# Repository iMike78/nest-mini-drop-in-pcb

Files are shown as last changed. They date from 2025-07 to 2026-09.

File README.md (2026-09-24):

<div align="right">
  <details>
    <summary >🌐 Language</summary>
    <div>
      <div align="center">
        <a href="https://openaitx.github.io/view.html?user=iMike78&project=nest-mini-drop-in-pcb&lang=en">English</a>
        | <a href="https://openaitx.github.io/view.html?user=iMike78&project=nest-mini-drop-in-pcb&lang=zh-CN">简体中文</a>
        | <a href="https://openaitx.github.io/view.html?user=iMike78&project=nest-mini-drop-in-pcb&lang=zh-TW">繁體中文</a>
        | <a href="https://openaitx.github.io/view.html?user=iMike78&project=nest-mini-drop-in-pcb&lang=ja">日本語</a>
        | <a href="https://openaitx.github.io/view.html?user=iMike78&project=nest-mini-drop-in-pcb&lang=ko">한국어</a>
        | <a href="https://openaitx.github.io/view.html?user=iMike78&project=nest-mini-drop-in-pcb&lang=hi">हिन्दी</a>
        | <a href="https://openaitx.github.io/view.html?user=iMike78&project=nest-mini-drop-in-pcb&lang=th">ไทย</a>
        | <a href="https://openaitx.github.io/view.html?user=iMike78&project=nest-mini-drop-in-pcb&lang=fr">Français</a>
        | <a href="https://openaitx.github.io/view.html?user=iMike78&project=nest-mini-drop-in-pcb&lang=de">Deutsch</a>
        | <a href="https://openaitx.github.io/view.html?user=iMike78&project=nest-mini-drop-in-pcb&lang=es">Español</a>
        | <a href="https://openaitx.github.io/view.html?user=iMike78&project=nest-mini-drop-in-pcb&lang=it">Italiano</a>
        | <a href="https://openaitx.github.io/view.html?user=iMike78&project=nest-mini-drop-in-pcb&lang=ru">Русский</a>
        | <a href="https://openaitx.github.io/view.html?user=iMike78&project=nest-mini-drop-in-pcb&lang=pt">Português</a>
        | <a href="https://openaitx.github.io/view.html?user=iMike78&project=nest-mini-drop-in-pcb&lang=nl">Nederlands</a>
        | <a href="https://openaitx.github.io/view.html?user=iMike78&project=nest-mini-drop-in-pcb&lang=pl">Polski</a>
        | <a href="https://openaitx.github.io/view.html?user=iMike78&project=nest-mini-drop-in-pcb&lang=ar">العربية</a>
        | <a href="https://openaitx.github.io/view.html?user=iMike78&project=nest-mini-drop-in-pcb&lang=fa">فارسی</a>
        | <a href="https://openaitx.github.io/view.html?user=iMike78&project=nest-mini-drop-in-pcb&lang=tr">Türkçe</a>
        | <a href="https://openaitx.github.io/view.html?user=iMike78&project=nest-mini-drop-in-pcb&lang=vi">Tiếng Việt</a>
        | <a href="https://openaitx.github.io/view.html?user=iMike78&project=nest-mini-drop-in-pcb&lang=id">Bahasa Indonesia</a>
        | <a href="https://openaitx.github.io/view.html?user=iMike78&project=nest-mini-drop-in-pcb&lang=as">অসমীয়া</
      </div>
    </div>
  </details>

</div>

# MiciMike drop-in PCB replacement for Google Nest Mini

[MiciMike Nest Mini](https://github.com/iMike78/nest-mini-drop-in-pcb) is a drop-in PCB replacement for the ["Google Nest Mini" (Google's second-generation smart speaker with a barrel connector charging port)](https://en.wikipedia.org/wiki/Google_Nest_(smart_speakers)), but based on ESP32 and XMOS microcontrollers for running open-source firmware.

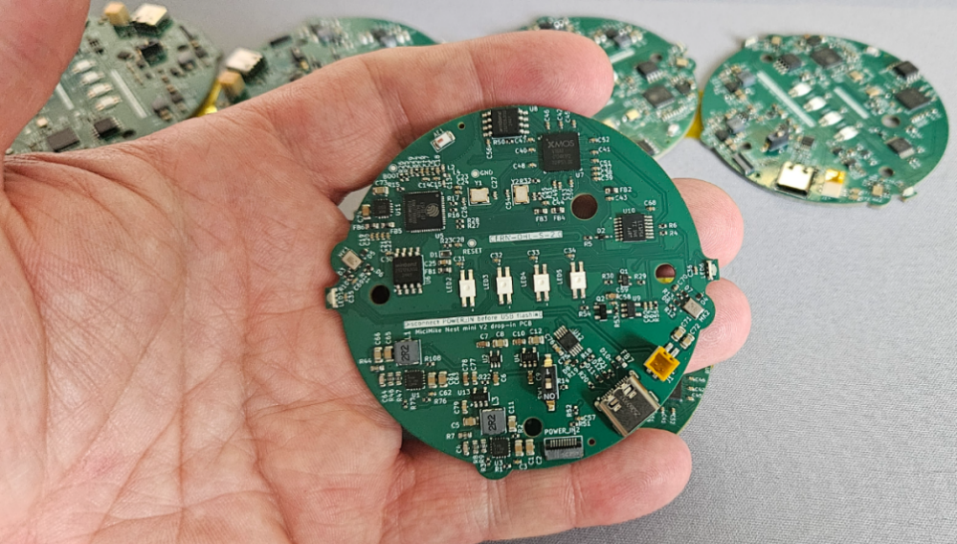
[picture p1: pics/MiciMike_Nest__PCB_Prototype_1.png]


Tip! If you are instead looking for a similar drop-in PCB replacement for the "Google Home Mini" (Google's first-generation smart speaker hardware with a Micro-USB charging port) then check out the sister-project at https://github.com/iMike78/home-mini-v1-drop-in-pcb

Both of these are fully open-source hardware projects, taking some concept inspiration from the [Onju Voice](https://github.com/justLV/onju-voice) however aiming to follow [Open Home Foundation's open voice assistants standard  with Home Assistant Voice Preview Edition as reference](https://www.home-assistant.io/blog/2024/12/19/voice-preview-edition-the-era-of-open-voice/) for PCB designs and specifications.

# Project scope

The goal of this project and repository (which is similar to the [Onju Voice](https://github.com/justLV/onju-voice) but under a fully open-source hardware license) is to design a custom drop-in replacement PCB (Printed Circuit Board) for the Google Nest Mini (2nd Gen).

This is primarly targeting people looking to convert/repurpose their old Google Nest Mini smart speakers into open-source hardware for [Voice Control of Home Assistant](https://www.home-assistant.io/voice_control/) and/or media player speaker output for [Music Assistant](https://www.music-assistant.io), (the hardware can however probably also be used with other applications as well with other firmware as it is based on the popular Espressif ESP32 platform).

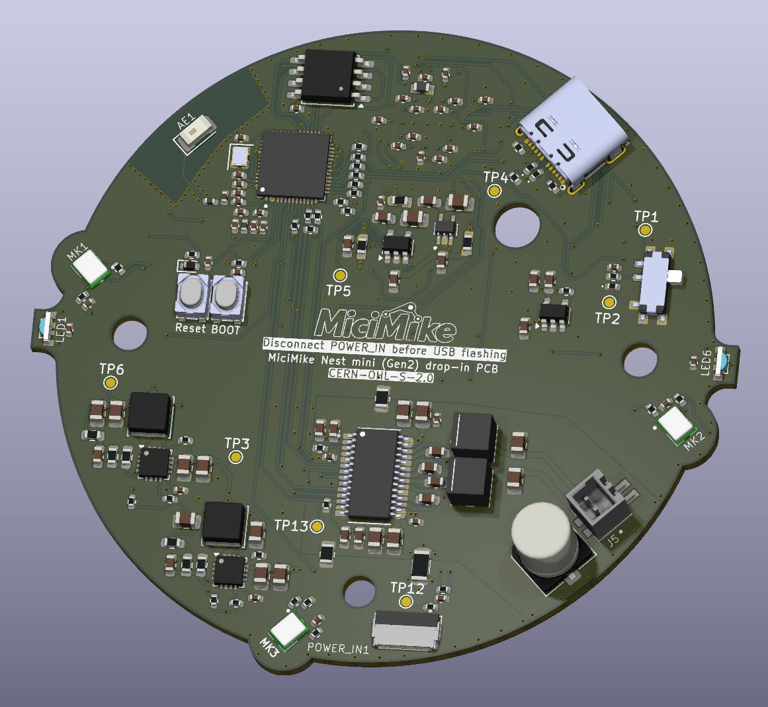
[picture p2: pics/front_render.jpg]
First test PCB


The hardware design will (similar to [Home Assistant Voice Preview Edition](https://www.home-assistant.io/blog/2024/12/19/voice-preview-edition-the-era-of-open-voice/)) integrate an ESP32-S3 SoC for WiFi, BLE, and [onboard wake-word detection](https://www.home-assistant.io/voice_control/about_wake_word/) (using no-code [ESPHome firmware](https://esphome.io/)) + an XMOS xCORE XU316 chip for advanced audio processing (with custom firmware for microphone cleanup offloading for better voice recognition capabilities by using using locally running algorithms for Noise Suppression, Acoustic Echo Cancellation, Interference Cancellation, and Automatic Gain Control).

Functionality-wise it is made to mostly hardware comatible with the [Home Assistant Voice Preview Edition (a.k.a. Home Assistant Voice PE](https://www.home-assistant.io/blog/2024/12/19/voice-preview-edition-the-era-of-open-voice/) reference design (which has been released as open-source hardware design from Open Home Foundation in coolaboration with Nabu Casa). The main difference will be due to constraints defined by the Google Nest Mini enclosure and comonents, (i.e. the nest-mini-drop-in-pcb project hardware design will be limited by the same type of physical capacity inputs as the original hardware from Google).

As such the scope of this project/repository is not to develop new features/functions for the ESPHome firmware, so if you want that then you instead need to turn to the firmware development of the Home Assistant Voice Preview Edition as well as to the upstream ESPHome mainline code:

- https://github.com/esphome/home-assistant-voice-pe
  - https://github.com/esphome/esphome
      - https://github.com/esphome/feature-requests

## Request for collaboration

If you have some experience with PCB layout design, (and epecially with PCB routing, ground pouring, or noise-sensitive digital+analog layouts), **your help is highly appreciated**! Please feel free to open a new issue, submit suggestions/requests, and add input/feedback to existing issues, or fork this repository.

For more information about the concept/idea see and contribute to related discussion also see this Home Assistant community forum thread:

- https://community.home-assistant.io/t/any-news-on-alternative-to-onju-voice-pcb-repacement-design-for-google-nest-home-mini-speakers-with-added-xmos-chip-to-match-of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

### Current status

> [!CAUTION]
> This project is under active development and is **not ready for fabrication or general use**. I do not recommend using the current files to manufacture a PCB.

The hardware is currently being substantially reworked, including the addition and integration of an ESP32-C6 for Thread support. As a result, parts of the schematic are incomplete, some components and connections are not yet placed or routed on the PCB, and the schematic and PCB may not be in sync.

The current ESPHome configuration also targets an earlier hardware revision and does not match the present schematic. It should not be treated as working firmware for the current board design.

Several known and newly reported hardware issues are being reviewed and will need to be corrected before another prototype revision is considered. These include the XMOS core power supply, parts of the XMOS audio and echo-cancellation reference path, a microphone buffer connection, XMOS debug-header voltage levels, mute detection, ESP32-C6 integration, and other smaller signal-level and connectivity issues.

Development and documentation updates have been slower recently due to limited availability and work on the related Home Mini project. The README and design files will be updated as the review and redesign progress.

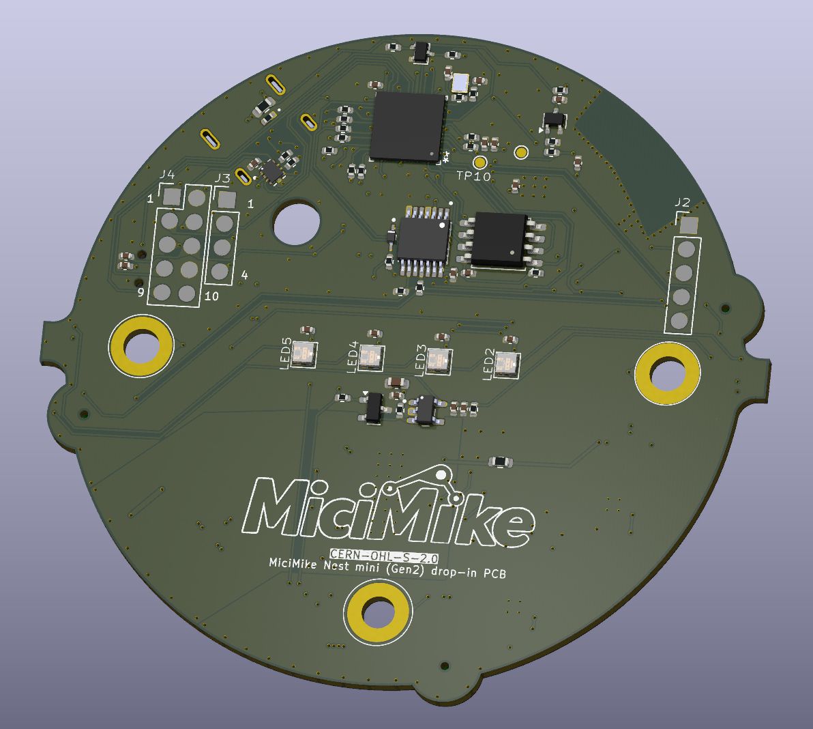
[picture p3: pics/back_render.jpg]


## Tools used

- 🛠️ KiCad 9
- 🧰 SnapEDA / LCSC for footprint sourcing

## Known hardware specifications

- 4-layer PCB
- ESP32-S3R8 bare chip (ESP32-S3 for WiFi, BLE, and onboard wake-word detection)
- XMOS XU316-1024-QF60B-C24 (XMOS XU316 xCORE DSP audio processing)
- 16 MB SPI flash (ESP32-S3)
- 4 MB SPI flash (XMOS XU316)
- Dual I²S buses (simultaneous audio input and output)
- TAS5805M (TAS5805MPWPR) stereo Class-D amplifier with integrated DSP (I2S audio, I2C control), configured for mono BTL speaker output
- 3x MEMS microphones (MMICT390200012) arranged on a 34 mm radius arc - current firmware uses 2 microphones, hardware support for a 3-microphone array is already present
- 6x SK6812 RGB LEDs
- Custom USB-C and 14V power input (Note! USB-C and barrel-connector can not be connected at the same time)
- MPR121 capacitive touch controller (used for touch input instead of ESP32-S3 native touch sensing)

---

> ⚠️ Flashing via USB-C requires disconnecting the main 14V power input. See silkscreen note on PCB for details.

## References

### Home Assistant Voice Preview Edition resources including PCB design files
- https://www.home-assistant.io/blog/2024/12/19/voice-preview-edition-the-era-of-open-voice/
  - https://voice-pe.home-assistant.io/resources/
    - https://support.nabucasa.com/hc/en-us/articles/26195279589277-Home-Assistant-Voice-Preview-Edition-PCB-design-files
      - https://raw.githubusercontent.com/NabuCasa/support/refs/heads/main/static/docs/voice/home_assistant_voice_pe_schematic_v1.0_241009.pdf
     
#### ESPHome firmware for Home Assistant Voice PE (which also use the same ESP32-S3 + XMOS XU316 combination):

- https://github.com/esphome/home-assistant-voice-pe
  - https://esphome.github.io/home-assistant-voice-pe/
- https://voice-pe.home-assistant.io/

### XMOS xCORE DSP (XU316-1024-QF60B-C24) MCU IC chip

- https://www.xmos.com/download/XU316-1024-QF60B-xcore.ai-Datasheet(3).pdf
- https://www.xmos.com/software-tools/
  - https://www.xmos.com/develop/xcore-voice
  - https://www.xmos.com/usb-multichannel-audio/
  - https://www.xmos.com/xcore-ai
 
#### XMOS firmware from the ESPHome project for the Home Assistant Voice Preview Edition hardware:

- https://github.com/esphome/voice-kit-xmos-firmware
  - https://github.com/esphome/xmos_fwk_rtos
  - https://github.com/esphome/xmos_fwk_io

## License

This project is licensed under the [CERN Open Hardware License Version 2 - Strongly Reciprocal (CERN-OHL-S v2)]
Any modified version of this hardware must also be distributed under the same license.

☕ If you’d like to support this project, feel free to [buy me a coffee on Ko-fi](https://ko-fi.com/imike78)!

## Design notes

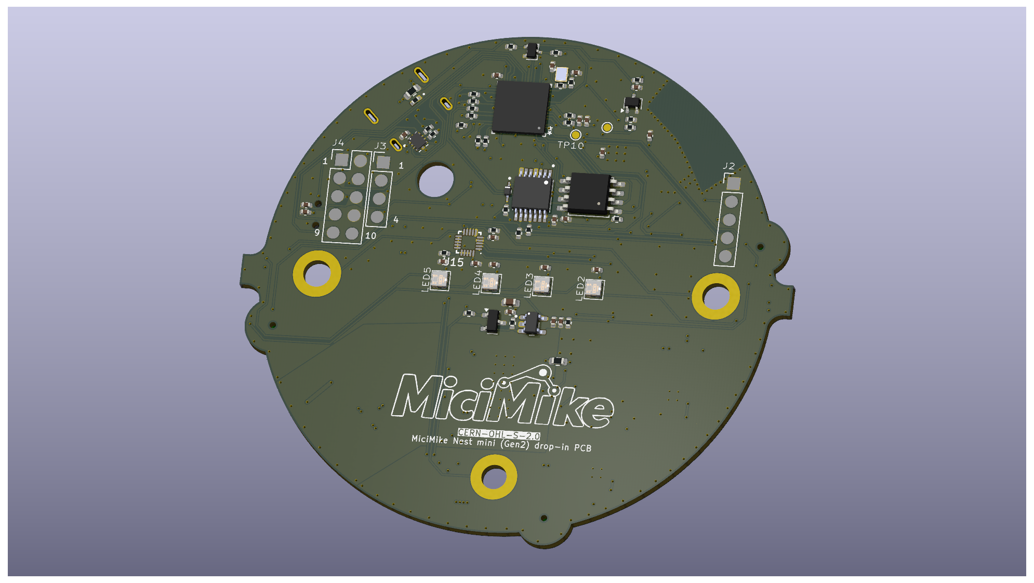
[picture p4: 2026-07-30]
pics/nest-mini-DiP-Gen2-back.png

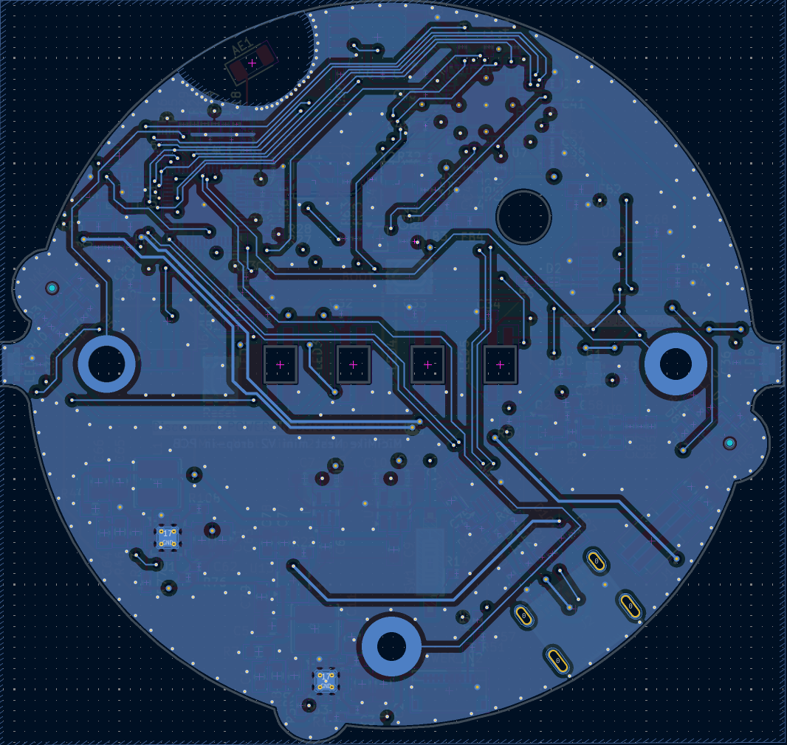
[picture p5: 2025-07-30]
pics/B_Cu.png

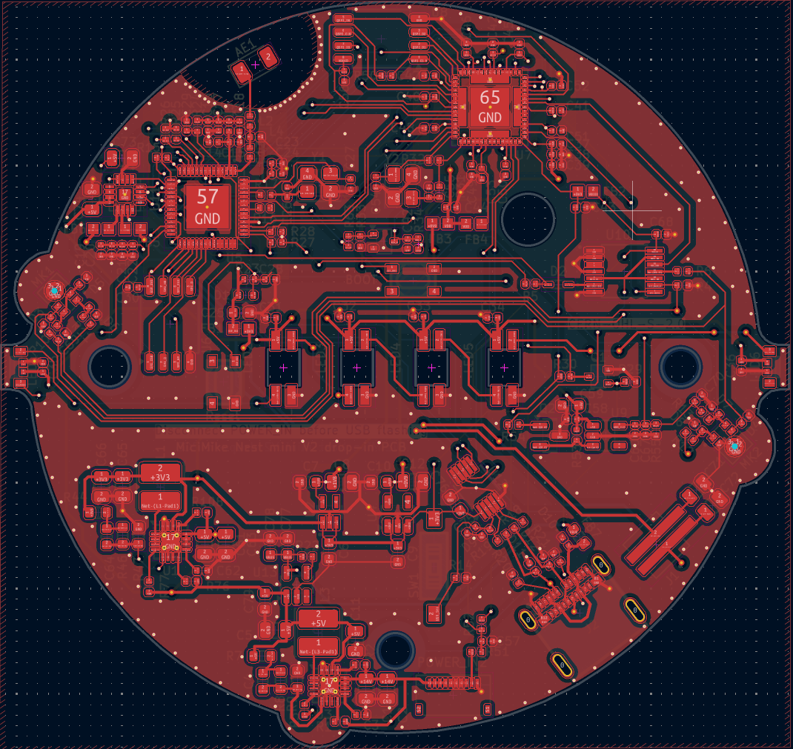
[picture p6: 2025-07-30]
pics/F_Cu.png

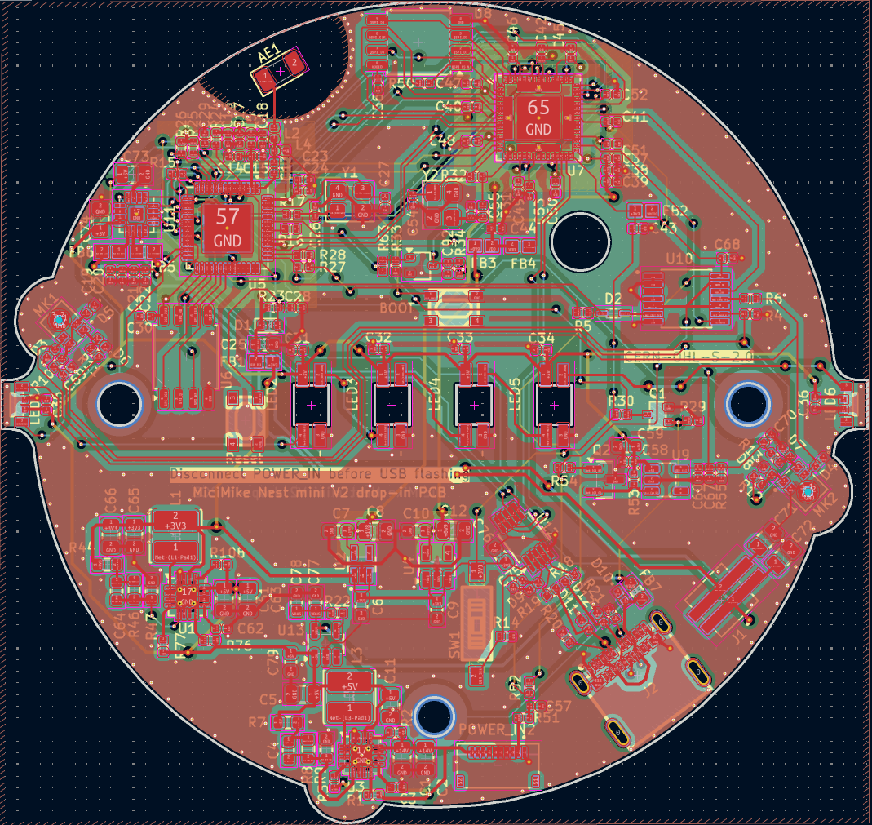
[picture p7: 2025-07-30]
pics/layout.png

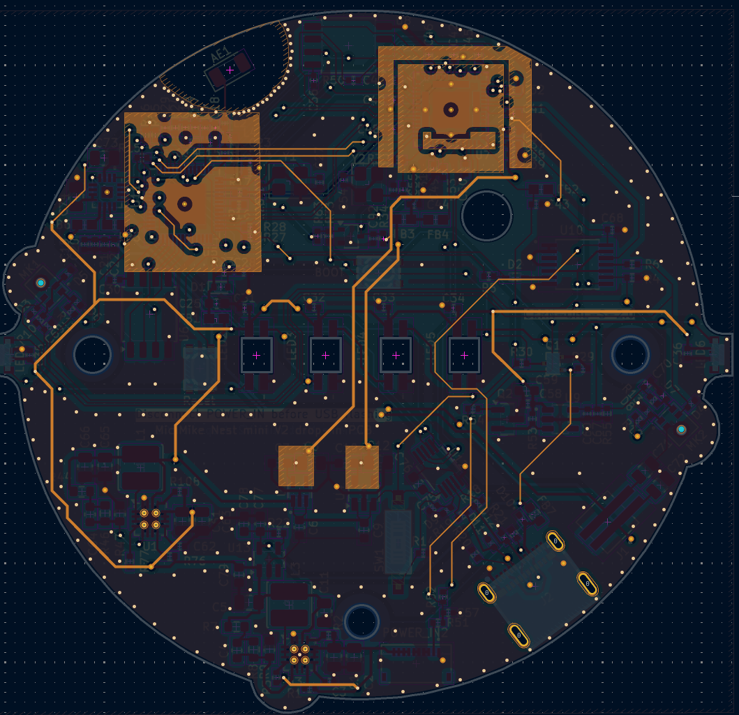
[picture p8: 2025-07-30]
pics/In2_Cu.png

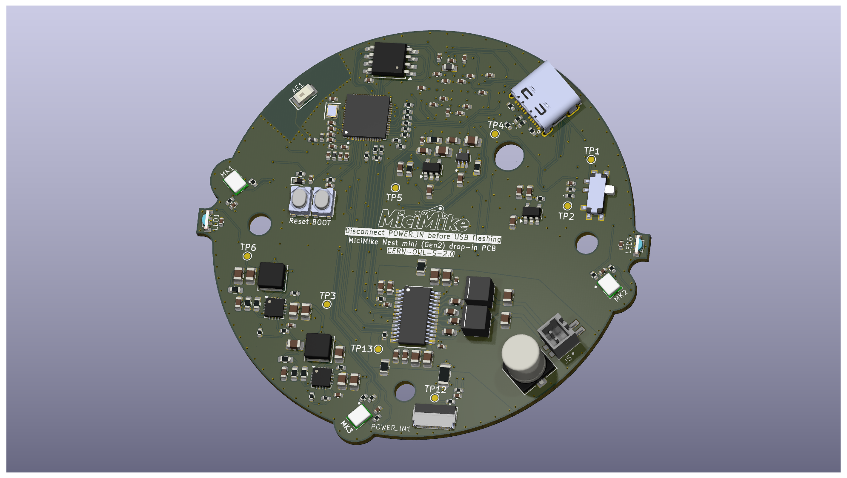
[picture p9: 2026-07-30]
pics/nest-mini-DiP-Gen2-front.png

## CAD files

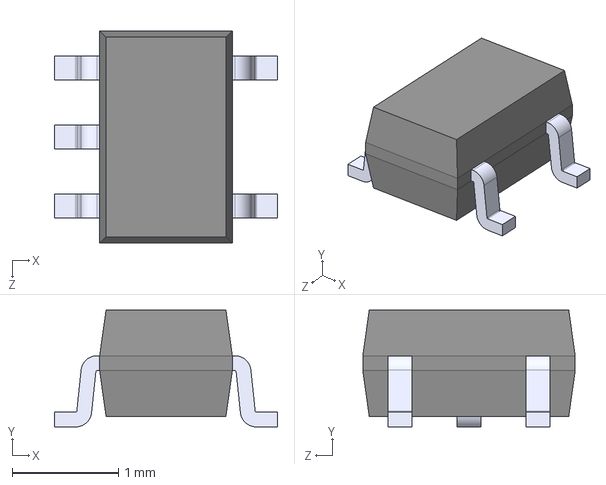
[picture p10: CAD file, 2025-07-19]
parts/MIC5365-1.8YC5-TR.step
2.10 x 1.10 x 2.00 mm

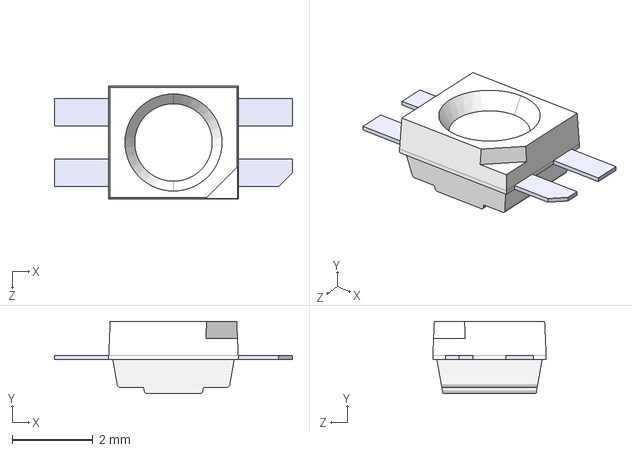
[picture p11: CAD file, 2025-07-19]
parts/SK6812-E.step
5.88 x 1.78 x 2.80 mm

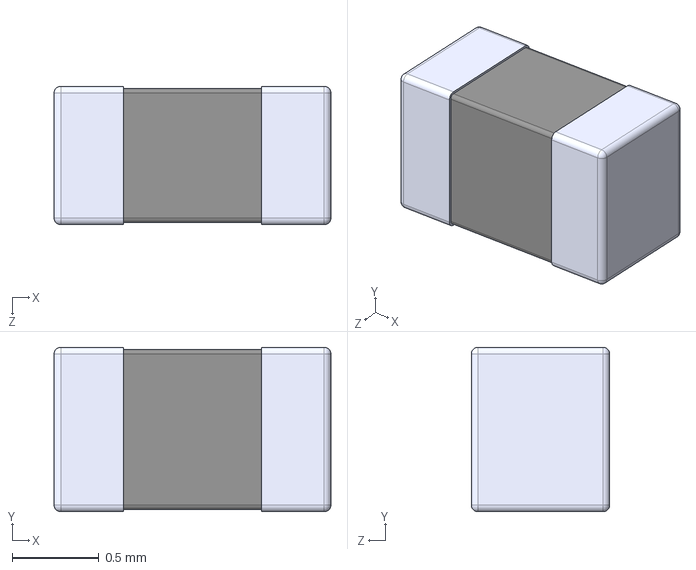
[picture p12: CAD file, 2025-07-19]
parts/BLM18PG121SN1D.step
1.60 x 0.95 x 0.8 mm

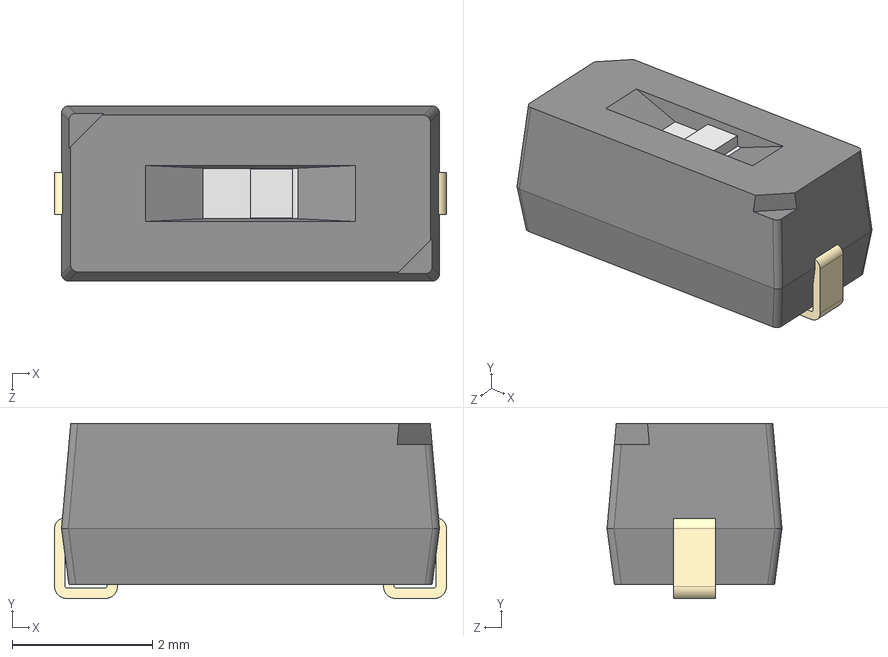
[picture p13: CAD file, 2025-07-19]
parts/CHS-01TA.step
5.60 x 2.50 x 2.50 mm
CHS-01 body
pin^CHS-01xx
switch^CHS-01xx

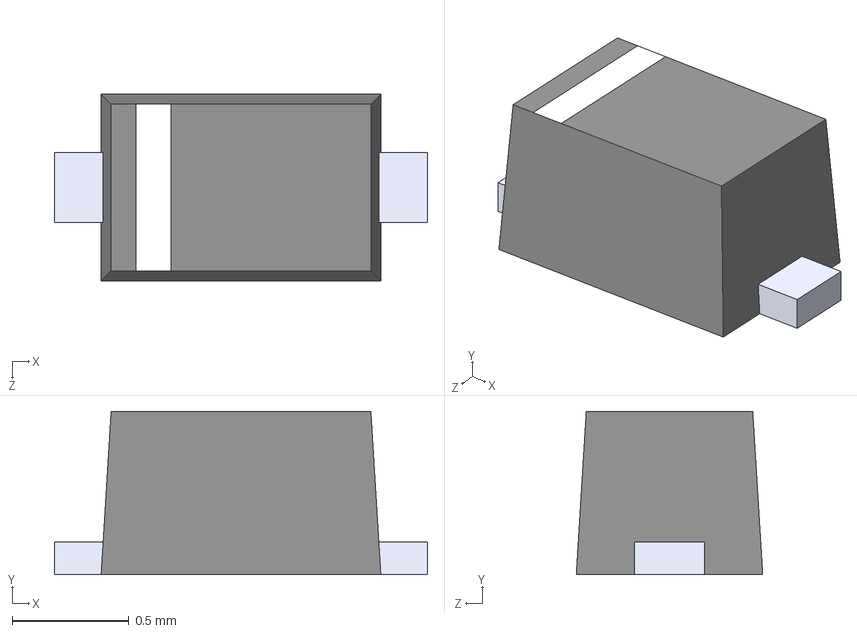
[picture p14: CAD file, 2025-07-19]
parts/RB521S30T1G.step
1.60 x 0.7 x 0.8 mm

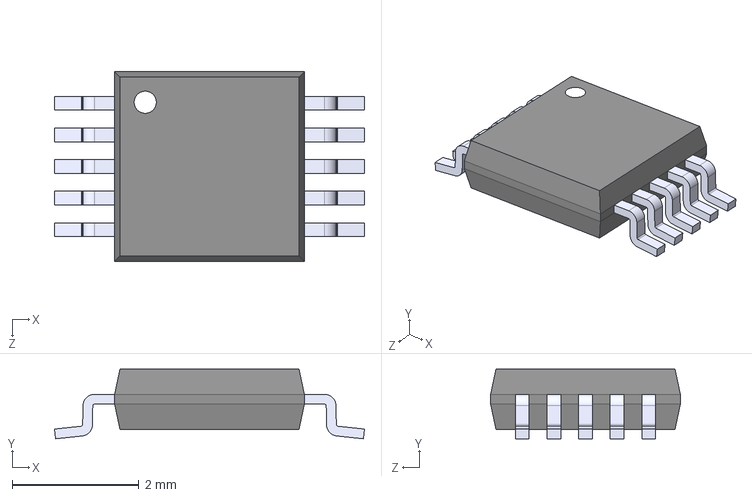
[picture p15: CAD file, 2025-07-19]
parts/FSUSB42MUX.step
4.90 x 1.10 x 3.00 mm

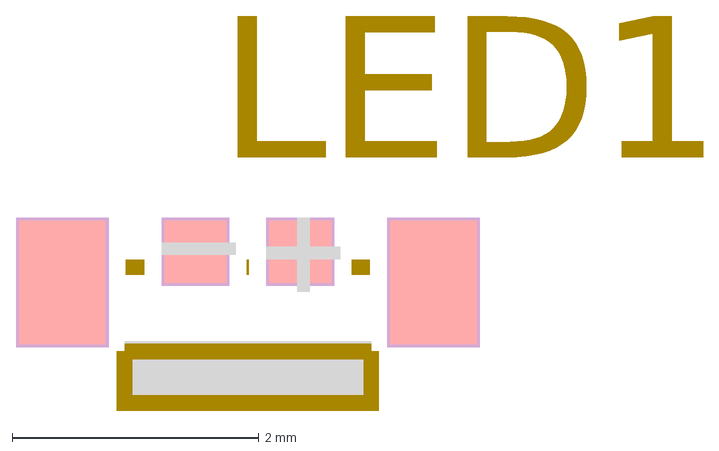
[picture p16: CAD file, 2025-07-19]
parts/SK6812D-EC3210R.dxf
LED1

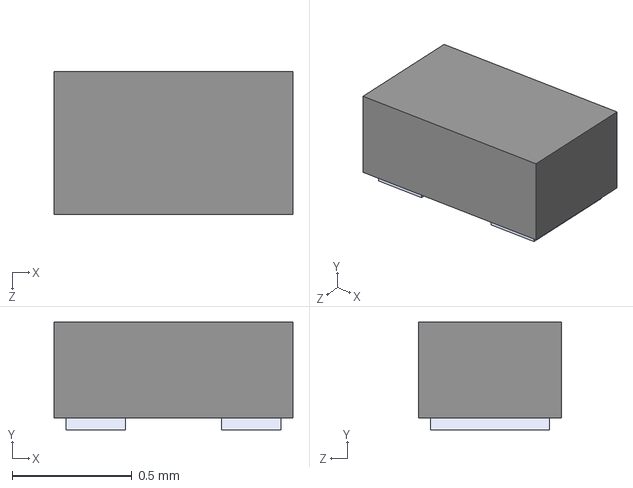
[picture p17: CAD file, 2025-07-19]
parts/TPD1E10B06DPYR.step
1.00 x 0.45 x 0.6 mm

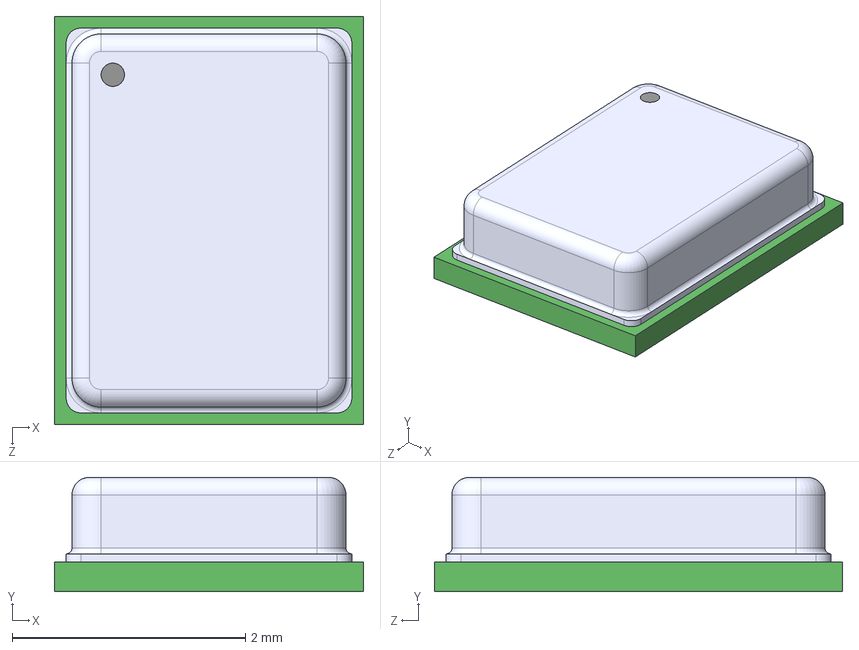
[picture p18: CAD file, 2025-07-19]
parts/T3902.step
2.65 x 0.98 x 3.50 mm

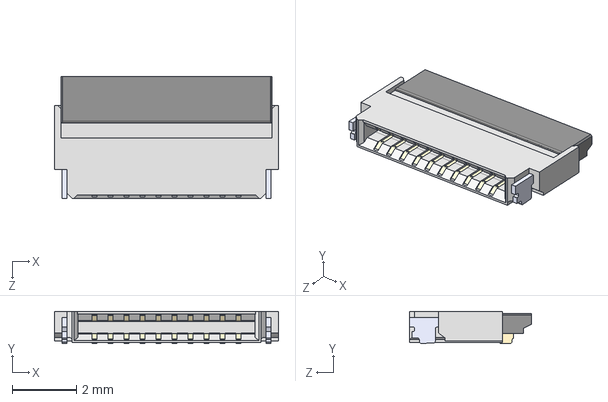
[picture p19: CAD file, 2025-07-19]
parts/FH34SRJ-10S-0.5SH_50_.step
7.00 x 1.00 x 3.80 mm

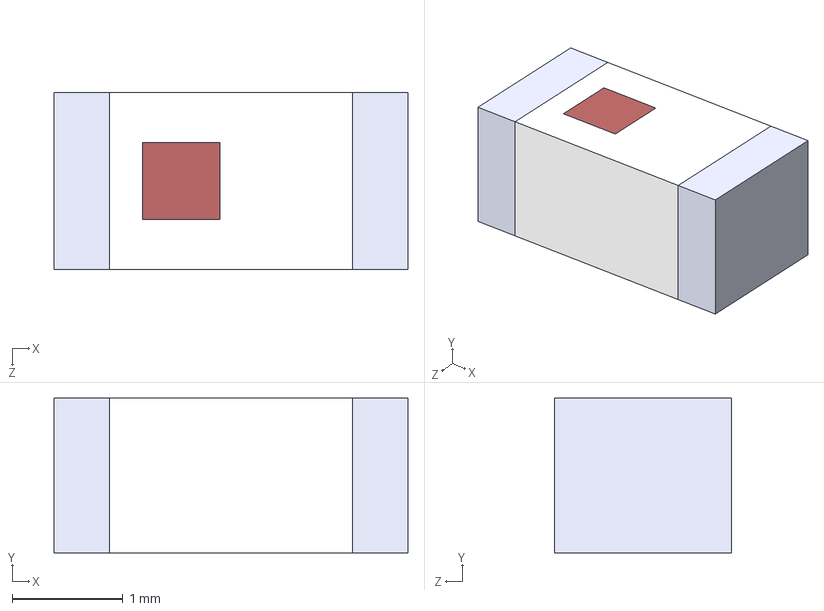
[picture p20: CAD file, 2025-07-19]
parts/2450AT18A100E.step
3.20 x 1.40 x 1.60 mm

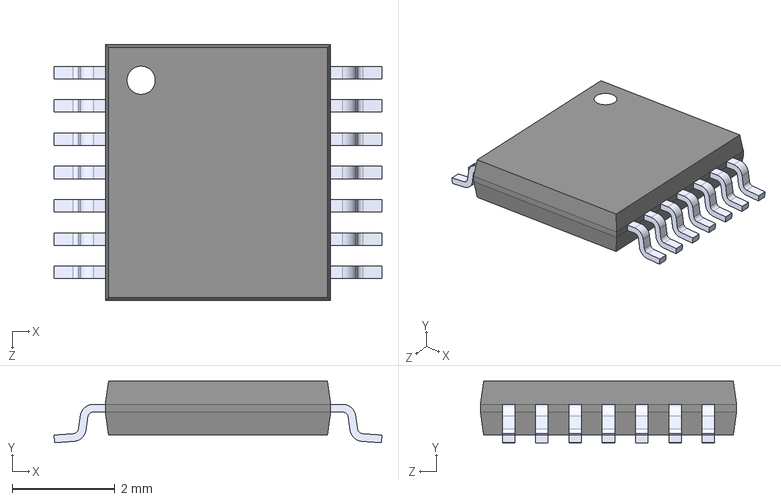
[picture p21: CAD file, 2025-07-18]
parts/SN74LVC125APWR.step
6.40 x 1.20 x 5.00 mm

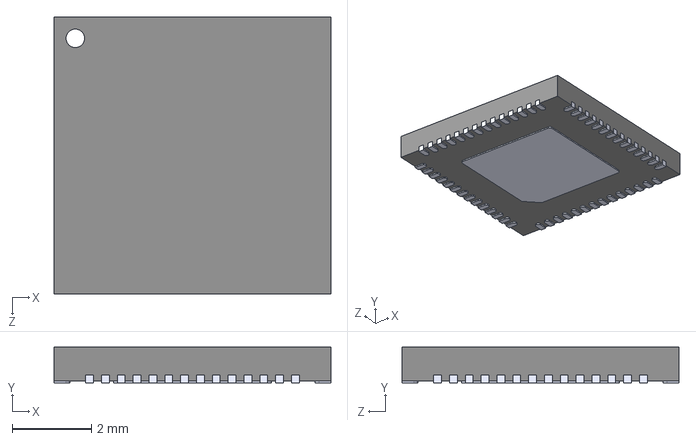
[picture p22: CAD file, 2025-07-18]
parts/ESP32-S3R8.step
7.00 x 0.9 x 7.00 mm

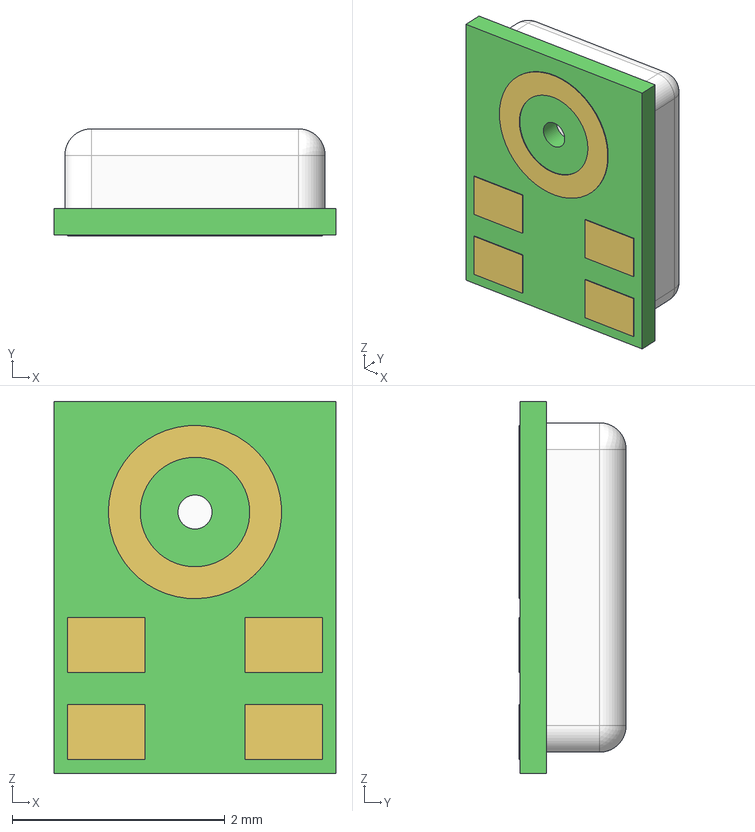
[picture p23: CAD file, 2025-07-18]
parts/DMM-3526-B-R.step
2.65 x 1.01 x 3.50 mm

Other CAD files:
parts/QFN_F60B-C24_XMO.step
parts/OBJ_SW-SMD_2P-L6.2-W2.5-LS9.4.obj
parts/SW-SMD_2P-L6.2-W2.5-LS9.4.dxf
parts/1054500101.obj
parts/1054500101.step
parts/1775443-2.stp
parts/MAX98357AETE_T.step
parts/TLV73333PDBVR.step
parts/TPS563201DDCT.step
parts/USB-C-SMD_TYPE-C-USB-18_2025-06-23.dxf
parts/USB_C_165068306/1054500101_3D.dxf

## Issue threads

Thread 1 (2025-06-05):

Will the first nest-mini-drop-in-pcb design use Dual I2S bus (same as Home Assistant Voice PE)?

Hedda, 2025-06-05:
Will the first nest-mini-drop-in-pcb design use "Dual I2S bus" (same as Home Assistant Voice PE)? As requested by @tetele for onju-voice here:

* https://github.com/justLV/onju-voice/issues/74

PS: For reference also see the somewhat related discussion here:

* https://github.com/orgs/FutureProofHomes/discussions/6

iMike78, 2025-06-11:
This isn’t really an issue, and the question is already answered — but yes, the design uses dual I²S buses, just like the Home Assistant Voice PE.
My work is strongly based on the HA VPE hardware design, so dual I²S with XMOS was a natural choice from the beginning.

Thanks for opening the thread and sharing the links, @Hedda!

Closed 2025-06-11.

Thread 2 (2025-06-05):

[REQUEST] PCB variant for the Google Home Mini (1st gen) speaker with Micro-USB charging port?

Hedda, 2025-06-05:
After the hardware design and firmware has matured (and been tested i the real-world for a while) like to suggest to please also consider designing a drop-in replacement PCB variant for the original/first-generation Google Home Mini with Micro-USB charging port.

https://www.ifixit.com/Device/Google_Home_Mini

https://www.ifixit.com/Guide/Google+Home+Mini+Disassembly/109922

https://www.ifixit.com/Teardown/Google+Home+Mini+Teardown/102264

FCC ID A4R-H0A

https://fccid.io/A4RH0A

https://fcc.report/FCC-ID/A4RH0A

Bet quite a few people also own many of the first-generation Google Nest Mini and are like myself interested in converting them as well.

https://www.dimensions.com/element/google-home-mini

The downsides to the first-generation Google Home Mini are a worse speaker and worse speaker array compared to the newer generation, (as well as that Micro-USB charging port however you would probably want to still keep it a Micro-USB charging port since all of them shipped with a Micro-USB charger power-adapter).

https://en.wikipedia.org/wiki/Google_Nest_(smart_speakers)

https://support.google.com/googlenest/answer/7072284

PS: FYI, for reference, see Google Home Mini (1st gen) request and related requests that was closed as "not planned" by the onju-voice developer:

* https://github.com/justLV/onju-voice/issues?q=is%3Aissue+is%3Aclosed+nest
  * https://github.com/justLV/onju-voice/issues/27
  * https://github.com/justLV/onju-voice/discussions/69
  * https://github.com/justLV/onju-voice/issues/28
  * https://github.com/justLV/onju-voice/issues/29
  * https://github.com/justLV/onju-voice/issues/36

Note! If you also want this and are a non-developer (e.g. only an end-user of Home Automation then suggest you only give a the top-post above a thumbs-up (in the bottom left) instead of just posting "+1", "me too", or other unspecific comments to this issue that is usually not directly constructive to the development and only serve as spamming. If you are a non-developers please feel free to post feedback to the Home Assistant's community discussions if it is things that are not directly constructive for the development. See -> https://community.home-assistant.io/t/any-news-on-alternative-to-onju-voice-pcb-repacement-design-for-google-nest-home-mini-speakers-with-added-xmos-chip-to-match-of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

PS: On a personal note I actually only own a single Google Nest Mini (Gen2) today, while I also own six of the Google Home Mini (Gen1), …as well as two original Google Home (pinapple), and two Google Home Max + two Google Nest Hub + five Chromecast Audio.

Hedda, 2025-06-27:
Quoting and cross-posting reply to comment by @iMike78 in https://community.home-assistant.io/t/any-news-on-alternative-to-onju-voice-pcb-repacement-design-for-google-nest-home-mini-speakers-with-added-xmos-chip-to-match-of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

Don't have the skills myself but I for one would be willing to donate money to you or someone else with the skills to figure that out if you could do to just by buying a few Google Home Mini (1st gen) from example eBay or other resellers that might sell new old stock (NOS) of them. Depns on which country you live in but there does seems to be a lot of inexpensive offers available for sale. Example:

* https://www.ebay.com/sch/i.html?_nkw=Google+Home+Mini+1st+gen

* https://www.ebay.com/sch/i.html?_nkw=google+home+mini+first+gen

* https://www.ebay.com/sch/i.html?_nkw=google+home+mini+first+generation

Hedda, 2025-06-27:
Doing some quick online searches for Google Home Mini ribbon cable pinout (for (Google Home Mini first gen found this:

* https://www.reddit.com/r/googlehome/comments/k34bo0/google_home_mini_pinout_answered/

Pin Function

1. Reset
2. Vcc
3. Vcc
4. Ground
5. D-
6. D+
7. Ground
8. Microphone Mute

Note 1 : Both Vcc pins (for power)) and both Ground pins are connected together. They are not separate circuits.

Note 2: As you look at the motherboard with the mounting point pointed down, the pins go from 8 to 1 (left to right). The ribbon cable has the pinouts numbered but it faces down so they are not visible unless you desolder the cable.

Here are also some information about how to best do a teardown to get to the PCB of Google Home Mini first generation:

* https://www.ifixit.com/Teardown/Google+Home+Mini+Teardown/102264
  * https://www.ifixit.com/Guide/Google+Home+Mini+Speaker+Replacement/109942
* https://www.allaboutcircuits.com/news/teardown-tuesday-google-home-mini/
* https://www.edn.com/teardown-googles-home-mini/
* https://justlv.medium.com/google-home-mini-teardown-comparison-to-echo-dot-and-giving-technology-a-voice-c59a23724a26
* https://www.instructables.com/Reupholster-Your-Google-Home-Mini/

PS: Slightly offtopic someone also wrote this blog about running custom code on the original Google Home which has more pics:

https://courk.cc/running-custom-code-google-home-mini-part1

iMike78, 2025-06-27:
💡 Since this will be a combined version, it means that no matter which type of Nest Mini you own (V1 or V2), you’ll be able to use the same board.
However! This also means you'll be paying for components that might not be necessary for your version.
That said, if you happen to have both models (or plan to mod more than one unit), the minimum order of 5 boards won't force you to order 5×V1 and 5×V2 – you'll just need 5 of this unified one. 😉

Closed 2025-08-05.

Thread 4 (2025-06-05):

MAX98357 Amplifier underpowered for the speaker inside the Google Nest Mini Gen2?

Hedda, 2025-06-05:
Reposting this question from @woody-539 posted to the onju-voice project:

* https://github.com/justLV/onju-voice/issues/82

Is the MAX98357 (digital amplifier from Maxim Integrated) underpowered for the speaker inside the Google Nest Mini Gen2?

Quote:

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

Noted there are different MAX98357 IC models, but all look to have a maximum output of  3,2 Watt @ 4 Ohm (3.2W at 4Ω,):

- https://www.digikey.se/sv/products/base-product/analog-devices-inc-maxim-integrated/175/MAX98357/110883

Adafruit has a lot more iformation in their PDF for their Adafruit MAX98357 I2S Class-D Mono Amp module:

- https://cdn-learn.adafruit.com/downloads/pdf/adafruit-max98357-i2s-class-d-mono-amp.pdf

  - https://learn.adafruit.com/adafruit-max98357-i2s-class-d-mono-amp/overview
  - https://www.adafruit.com/product/3006

Specs:

* Output Power: 3.2W at 4Ω, 10% THD, 1.8W at 8Ω, 10% THD, with 5V supply
* PSRR: 77 dB typ @ 1KHz
* I2S sample rates from 8kHz to 96kHz
* No MCLK required
* Click + Pop reduction
* Five pin-selectable gains: 3dB, 6dB, 9dB, 12dB, 15dB
* Excellent click-and-pop suppression
* Thermal shutdown protection

cr7pt0gr4ph7, 2025-06-06:
To clarify for others reading this: The specs of the speaker in the official Google store on Amazon specify it as having 15W:

* https://www.amazon.com/Google-Bluetooth-Language-Compatibility-Assistant/dp/B0DQWWWPGP

But when you disassemble the original hardware (2nd gen, can't speak about 1st gen as I don't have the latter), it contains a MAX98357 audio amplifier which has the mentioned limitations.

cr7pt0gr4ph7, 2025-06-06:
The MAX98373 is not publicly available, and [neither is its data sheet](https://ez.analog.com/other-products/w/documents/33127/how-can-i-get-the-datasheet-for-max98373),  but as [stated by the manufacturer](https://ez.analog.com/other-products/w/documents/33127/how-can-i-get-the-datasheet-for-max98373), the MAX98374 has identical specs.

I could not identify the speaker model, but measured it to have an impedance of 4 Ohms. Based on the data sheet for the MAX98374, the power supply voltage of 14V and the impedance of 4 Ohms, it seems likely that the speaker is driven with somewhere between 12W and 15W.

iMike78, 2025-06-09:
The Nest mini V2 power adapter is capable to pump out 15 watts (14V 1.1A) max, so even if the speaker is a 15W speaker, that's never driven by 15W.

Closed 2025-06-11.

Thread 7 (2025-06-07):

Utilize KiCad integrated support for Git version control to submit pull requests and do commits?

Hedda, 2025-06-07:
Suggest consider ulilizing ”KiCAD Git integration” to use KiCAD’s integrated support for Git version control to submit pull requests and do commits (instead of uploading files directly to this repo via web uploads). That way each change and commit can be tracked to a pull request as well. See:

- https://docs.kicad.org/9.0/en/kicad/kicad.html#git_integration

More backstory about KiCAD Git integration here:

- https://forum.kicad.info/t/tutorial-how-to-enable-git-in-kicad-8/49235

Maybe also check out this indirectly related optional plug to perform Git actions directly from KiCad's PCB editor window?

- https://github.com/adamws/kicad-git

This is a copy of the suggestion from @cr7pt0gr4ph7 posted posted as a BTW tip in issue https://github.com/iMike78/nest-mini-drop-in-pcb/issues/6

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

Closed 2025-06-15.

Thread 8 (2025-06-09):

Enable a "GitHub Discussions" section to this repository that can be used for non-issues?

Hedda, 2025-06-09:
Please consider enabling "GitHub Discussions" section to this repository that can be used as a community forum for non-issues questions & answers.

- https://docs.github.com/en/discussions/quickstart

GitHub Discussions are meant for repository specific community conversations directly on GitHub without havig to use issues or any tracking.

- https://docs.github.com/en/discussions/collaborating-with-your-community-using-discussions/about-discussions

Discussions are primarly meant for ongoing open-ended discussions that unlike issues do not need to be closed as resolved, but can be kept open.

- https://resources.github.com/devops/process/planning/discussions/

@iMike78 Note that you as repo admin/owner will be able to move discussions to issues and vice versa or cross-referencing if needed. See:

- https://docs.github.com/en/discussions/guides/best-practices-for-community-conversations-on-github

"_You can use discussions to brainstorm with your team, and eventually move the conversation to an issue when you are ready to scope out the work._"

You can also do other stuff like pinning important topics, etc.

- https://docs.github.com/en/discussions/managing-discussions-for-your-community/managing-discussions

_With GitHub Discussions, the community for your project can create and participate in conversations within the project's repository or organization. Discussions empower a project's maintainers, contributors, and visitors to gather and accomplish the following goals in a central location, without third-party tools._

* Share announcements and information, gather feedback, plan, and make decisions
* Ask questions, discuss and answer the questions, and mark the discussions as answered
* Create polls to gauge community opinion
* Upvote discussions and comments to give higher visibility to ideas you find valuable
* Foster an inviting atmosphere for visitors and contributors to discuss goals, development, administration, and workflows

PS: Such a repo discussions section could contain all conversations that are dedicated to this specific PCB board project. So stuff not belonging here:

* https://community.home-assistant.io/t/any-news-on-alternative-to-onju-voice-pcb-repacement-design-for-google-nest-home-mini-speakers-with-added-xmos-chip-to-match-of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

iMike78, 2025-06-11:
Hi @Hedda
Discussions section is enabled now.

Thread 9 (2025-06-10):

(suggestion) Add pins in the PCB to power the device, without using usb-c or jack cables (5v directly)

luckyzor, 2025-06-10:
All in the title, don't know if is possible though...
For a ceiling installation, avoid sockets/plugs is a must.

Thanks

iMike78, 2025-06-11:
As this is a standalone desktop/wall hanging speaker, to use it as it is, with the speaker fitted, the PCB is not accessible at all. That's the reason why I can't see why should I add an extra 5V input.

Closed 2025-06-11.

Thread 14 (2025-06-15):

How does this PCB design achieve galvanic isolation for audio output and audio input?

Hedda, 2025-06-15:
How is galvanic isolation achieved for audio output and audio input?

https://en.wikipedia.org/wiki/Galvanic_isolation

Have you put components and circuits like example opto-isolators on the board to prevent this from ever happening or can a user get issues if they for example a third-party power-supply that is properly galvanicly isolated?

”_Galvanic Isolation is electrical isolation between two circuits. A transformer provides galvanic isolation because there is no direct electrical connection between the primary and secondary windings; the audio signal is passed via magnetic coupling. An opto-coupler also provides galvanic isolation, as the signal is passed via light modulation._”

https://www.psaudio.com/blogs/ask-paul/galvanic-isolation-explained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

Now this question is above my head as I do not know much about electrical engineering myself but I still want to raise the question because from personal experince I had poor experince with a few powered speakers when using them with an audio source that presumably is grounded differently. I understand the problem can also give symtoms of noise if using a third-party power-supply that

 To solve my own problem I personally just bought a cheap in-line galvanic isolator in the power signal path between audio source and the amplifier or powered speaker, but understand that a better way might been to buy a better power-supply that is properly galvanicly isolated.

iMike78, 2025-06-15:
Did you see any audio input or output in this project?

Hedda, 2025-06-15:
No, but it has power input.

iMike78, 2025-06-15:
This project is designed as a drop-in replacement for the original Nest/Onju PCB, so the original power supply is expected to be reused.
Just like the Onju reference design, this project does not implement galvanic isolation — it hasn’t proven necessary in that context.

Closed 2025-06-15.

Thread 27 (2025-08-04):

[SUGGESTION] Add picture(s) of the prototype PCB and/or CAD image to the readme file as preview?

Hedda, 2025-08-04:
Suggest add some picture to the`README.md` file that show PCB mounted.

Noted @iMike78 already posted pictures in discussion sections of old prototype PCBs so maybe upload those first to get it rolling?

- https://github.com/iMike78/nest-mini-drop-in-pcb/discussions/15

- https://ko-fi.com/imike78

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

PS: The inspiration is to get a nicer readme to promote this, similar to how the readme file for the onju-voice project has these:

- https://github.com/justLV/onju-voice/blob/master/README.md

  - https://github.com/justLV/onju-voice/blob/master/README.md#onju-voice-

  - https://github.com/justLV/onju-voice/blob/master/README.md#-hardware

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

Hedda, 2025-08-04:
While not needed now I still think it is a good idea to have such pictures before you publishing it on PCBWay because it acts as a promotion. The thinking is that a better presentation once published PCBWay and will make more tech-reviewers and other people interersted in linking to the project, and then the news will spread via word of month.

This reflects in the very common proverb; "_**a picture is worth a thousand words**_"  which means that a single image can convey a complex idea or story more effectively than a lengthy verbal description. It highlights the power of visual communication and how a well-chosen image can capture a moment, emotion, or concept more vividly and efficiently than a long explanation. 😉

PS: FYI; you should know that if and when you publish it under shared projects on PCBWay then you will get a small commision from them for each PCB sold, ("_PCBWay Donate 10% cost To Author_"), and I believe is partially a good presentation is why Onju Voice is still ranked high on PCBWay shared projects:

* https://www.pcbway.com/project/shareproject/

  * https://www.pcbway.com/project/shareproject/Onju_Voice_d33625a1.html

Closed 2025-08-31.

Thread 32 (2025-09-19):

(Suggestion) Position of usb-c

GegoSK, 2025-09-19:
Probably too late, but is it possible to place the usbc connector at position, that the cable could be connected and pulled out around the speaker through the hanging hole? I tried to do something like that with onju, but microusb connector is to tall. There should be enought space for cable around speaker. It could be useful for firmware upload in case uploading via wifi is not working or possible.

I sent you a coffee. Thank you for this project!

PS: I read in another topic, where you mentioned "_replacement of different smart speakers_". Just a inspiration - https://www.mi.com/global/product/mi-smart-speaker. I have one, it has better sound than Google nest.

GegoSK, 2025-09-27:
> First of all, there is a reason why the USB-C connector in vertical position, and we have discussed it earlier. Second, I like your suggestion about the Xiaomi speaker, but as I don't own one, I can't work on it.

Just out of curiosity, what was the reason?

Would you need some information or photos firstly? Or should I provide you one speaker? ;-)  I found second hand on sale.

iMike78, 2025-09-27:
The main reason is printed on the PCB as well. The POWER_IN and USB can not be connected in the same time, so the position of the port forcing you to remove the PCB (and disconnect the FPC) before you connect the USB. Your use case scenario is specific.
The other reason is as we need a full version of USB-C connector because of the flashing capability, the horizontal version of that won't fit into the case as that one is way taller than the micro USB.

Before I start to work any other variant of smart speaker I'll need to confirm this one working. So at this time there is no reason to source one.

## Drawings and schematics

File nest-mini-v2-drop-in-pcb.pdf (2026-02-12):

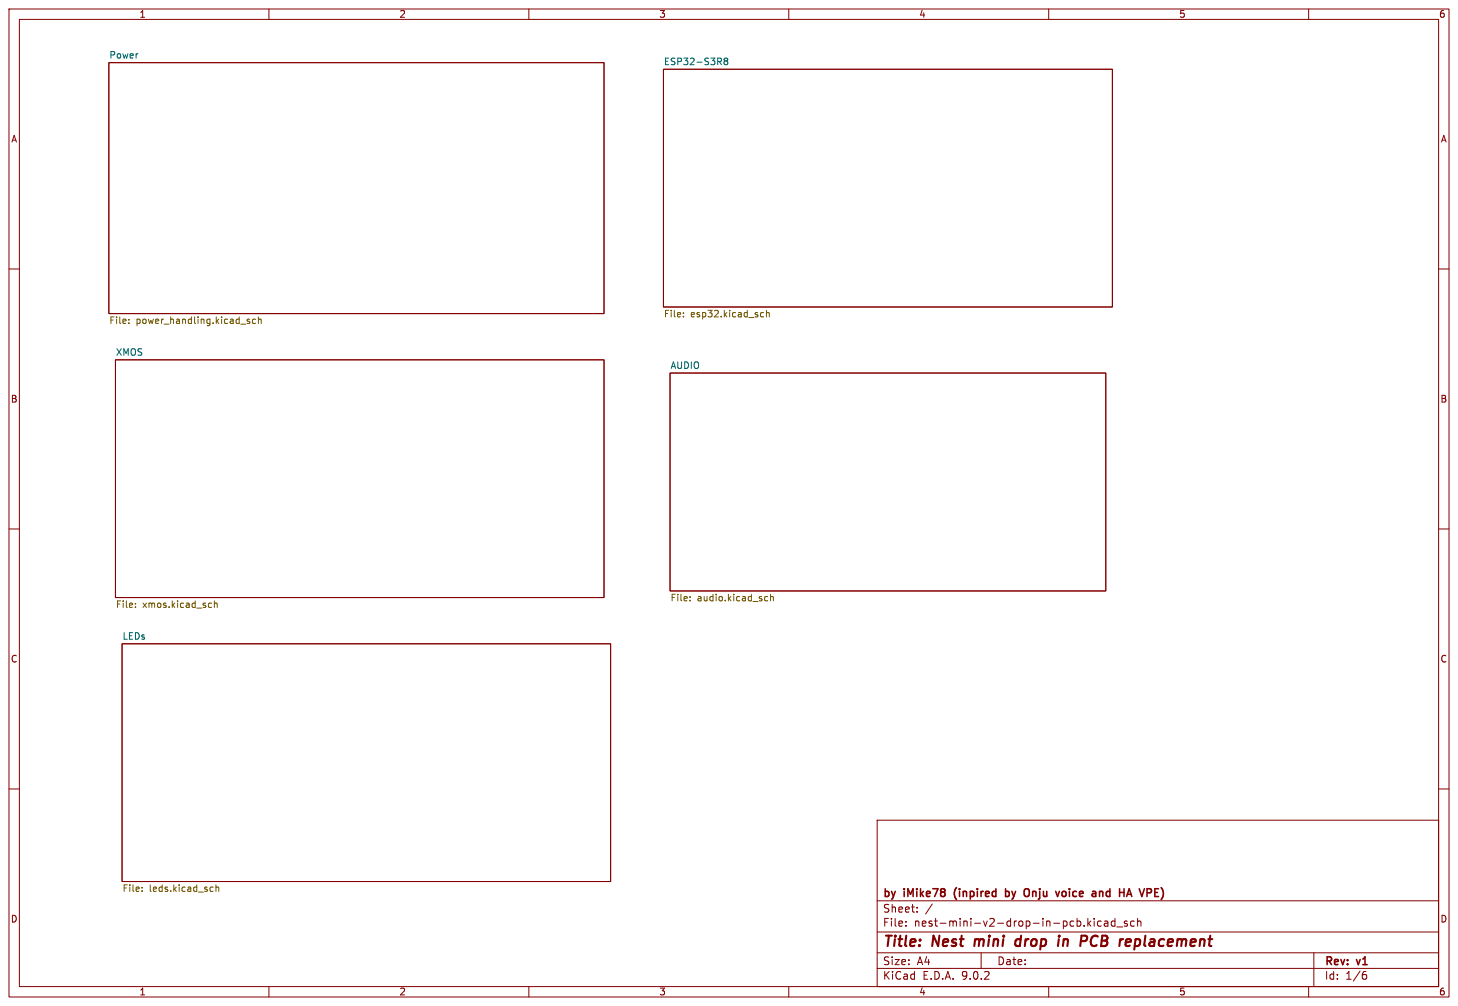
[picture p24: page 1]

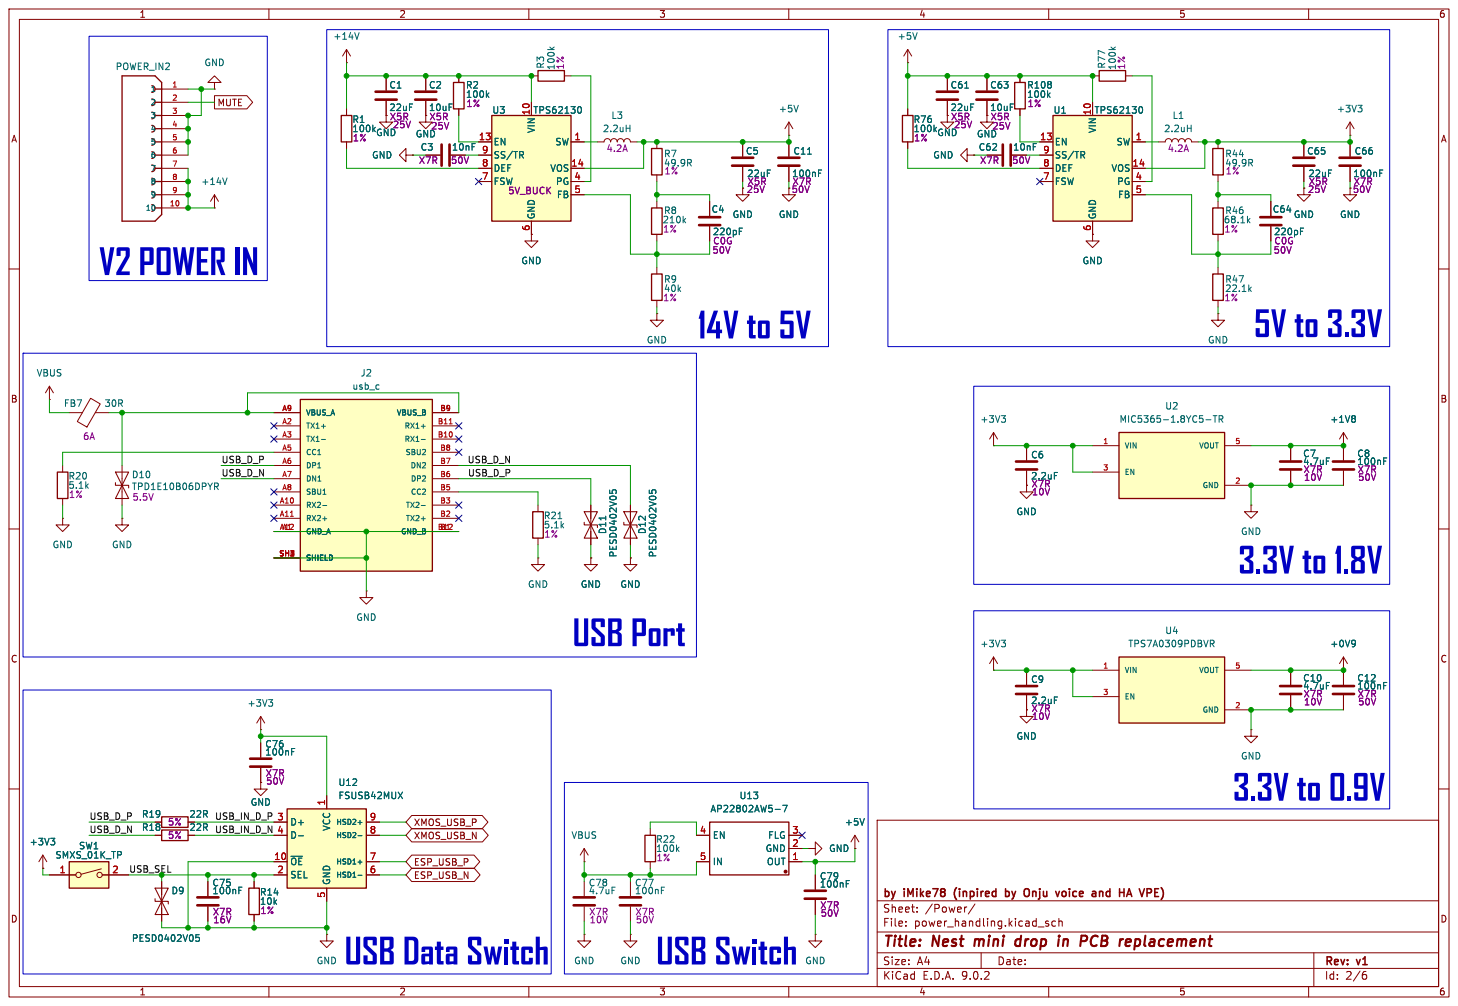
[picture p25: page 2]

6 SW 1 VOS 14 PG 4 FB 5 U3 TPS62130

6 SW 1 VOS 14 PG 4 FB 5 U1 TPS62130 R76

6 SW 1 VOS 14 PG 4 FB 5 R76

6 SW 1 VOS 14 PG 4 FB 5 GND GND GND

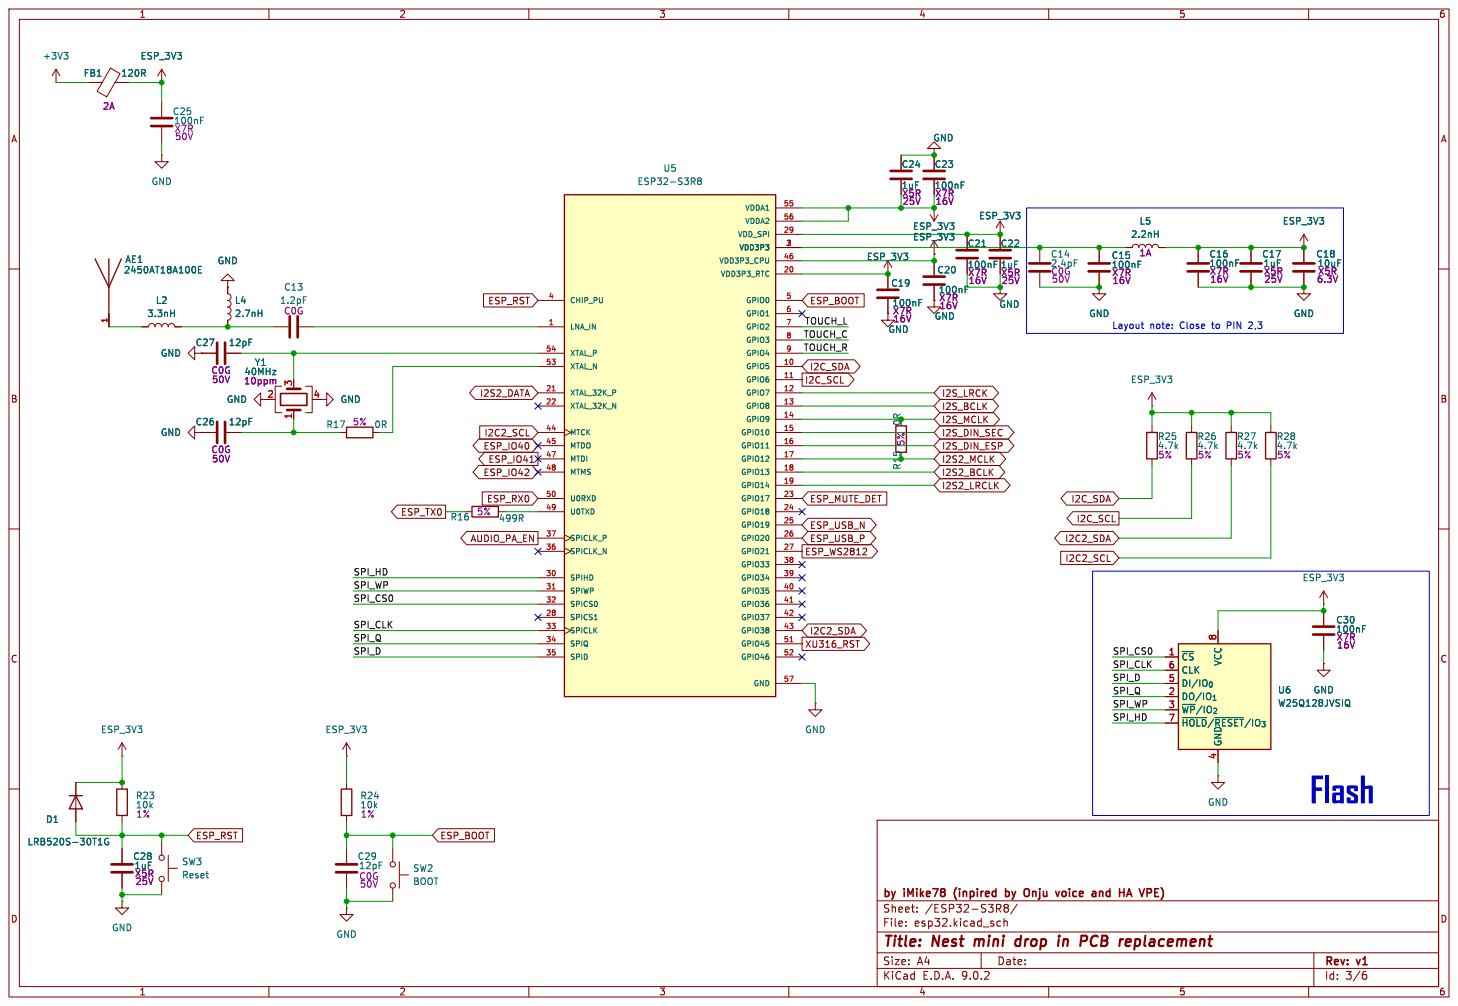
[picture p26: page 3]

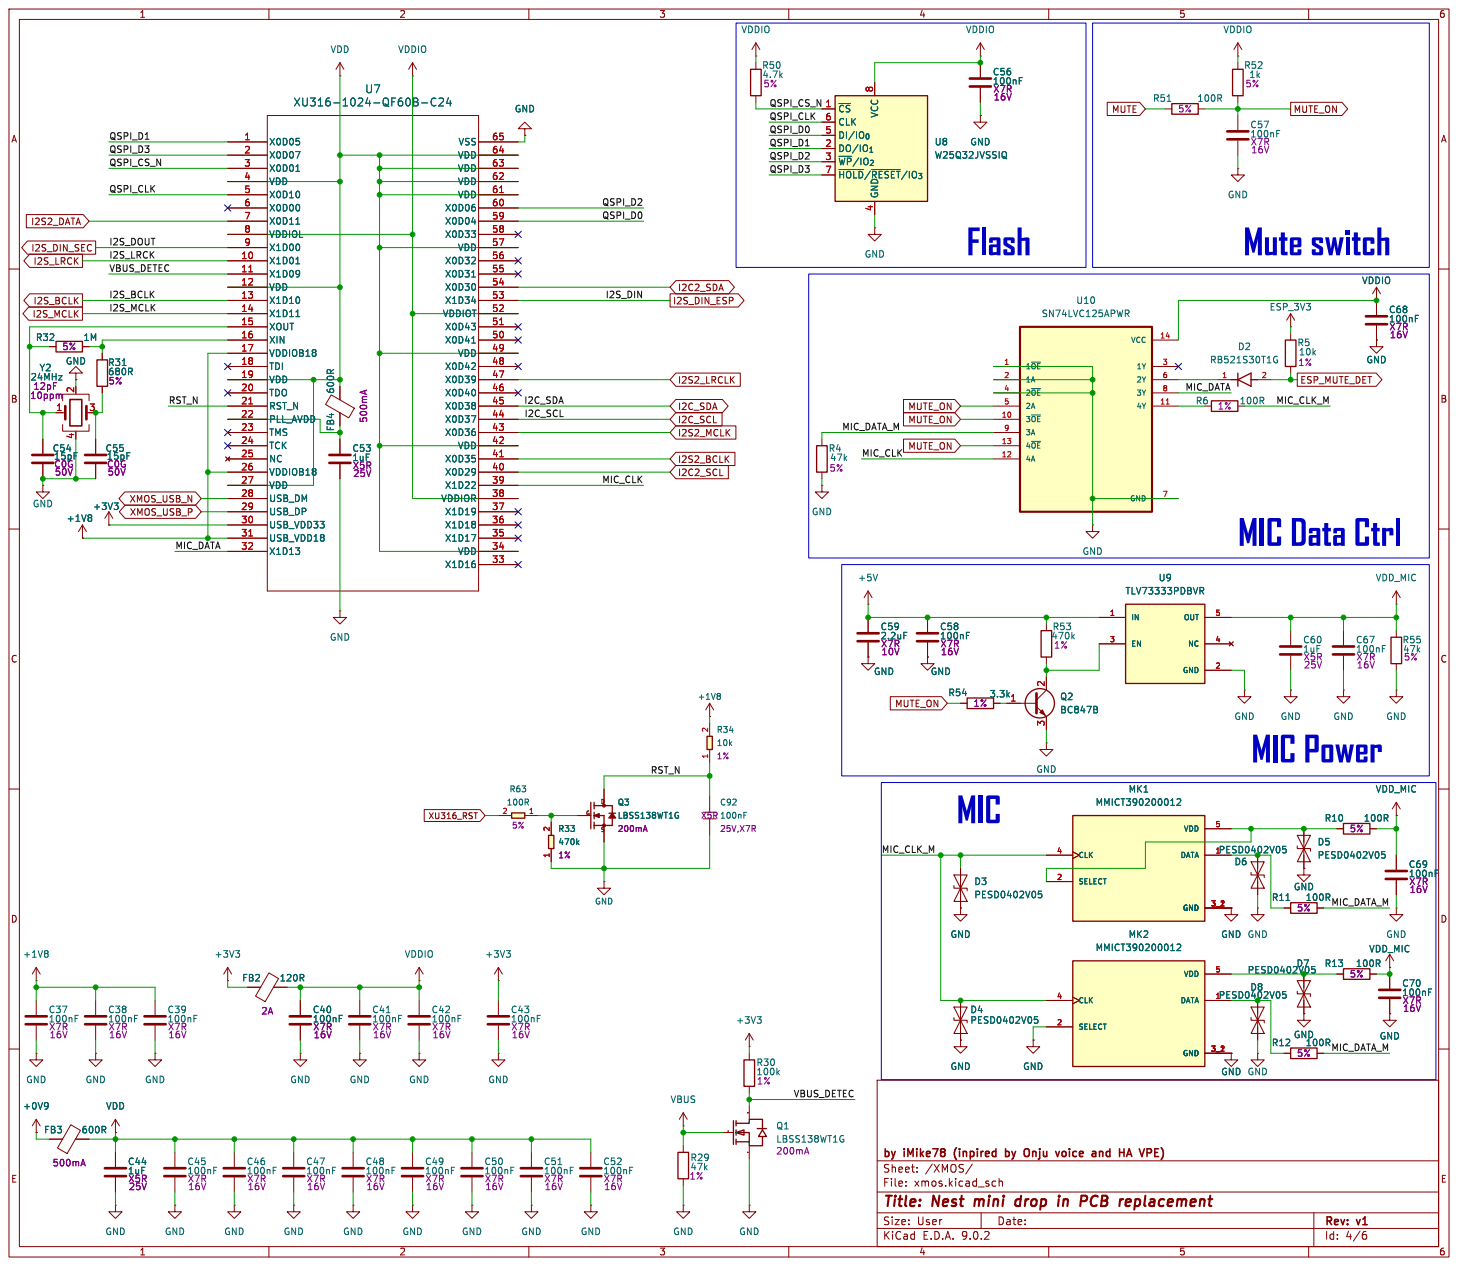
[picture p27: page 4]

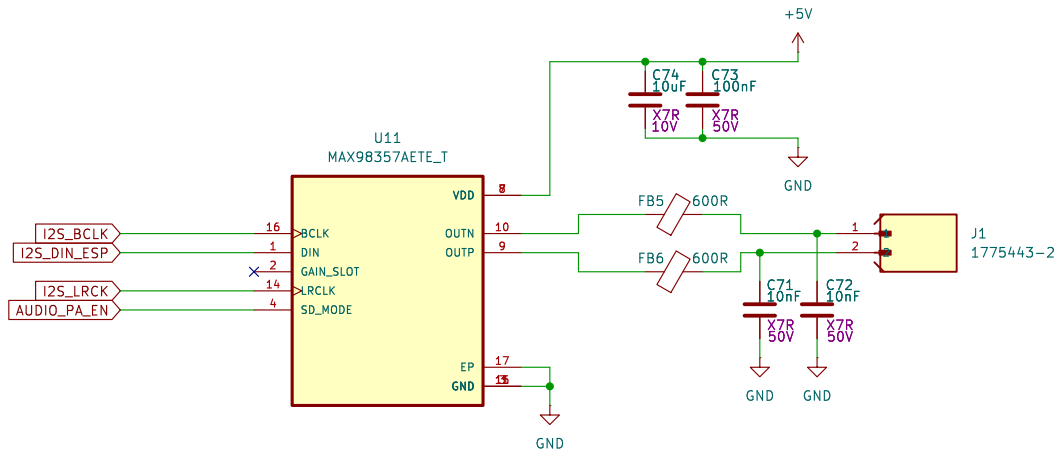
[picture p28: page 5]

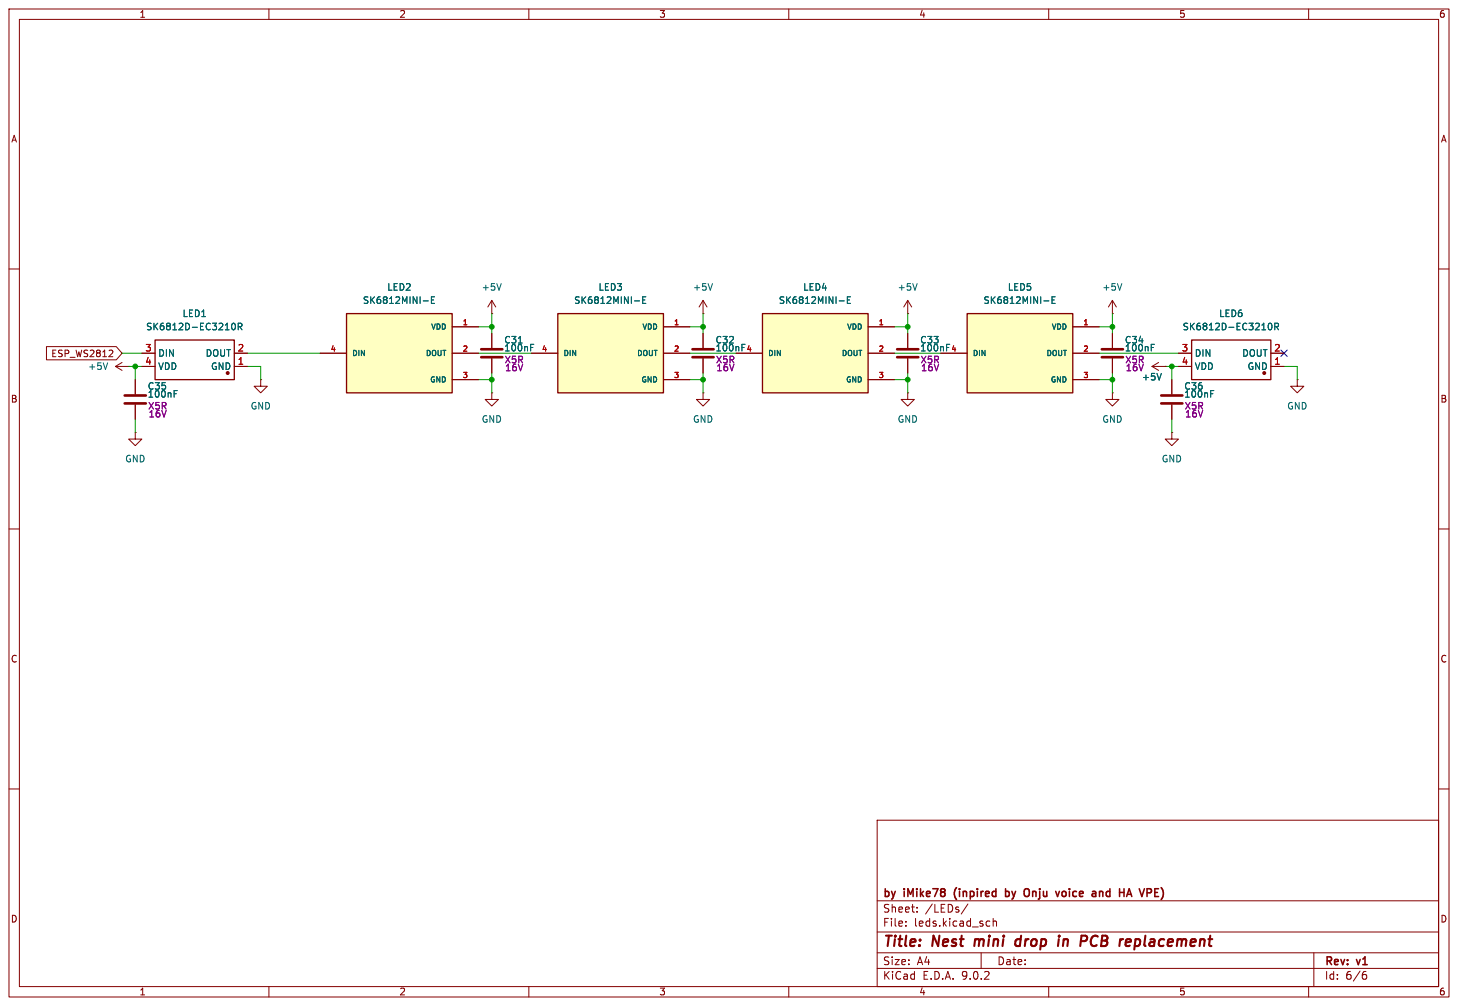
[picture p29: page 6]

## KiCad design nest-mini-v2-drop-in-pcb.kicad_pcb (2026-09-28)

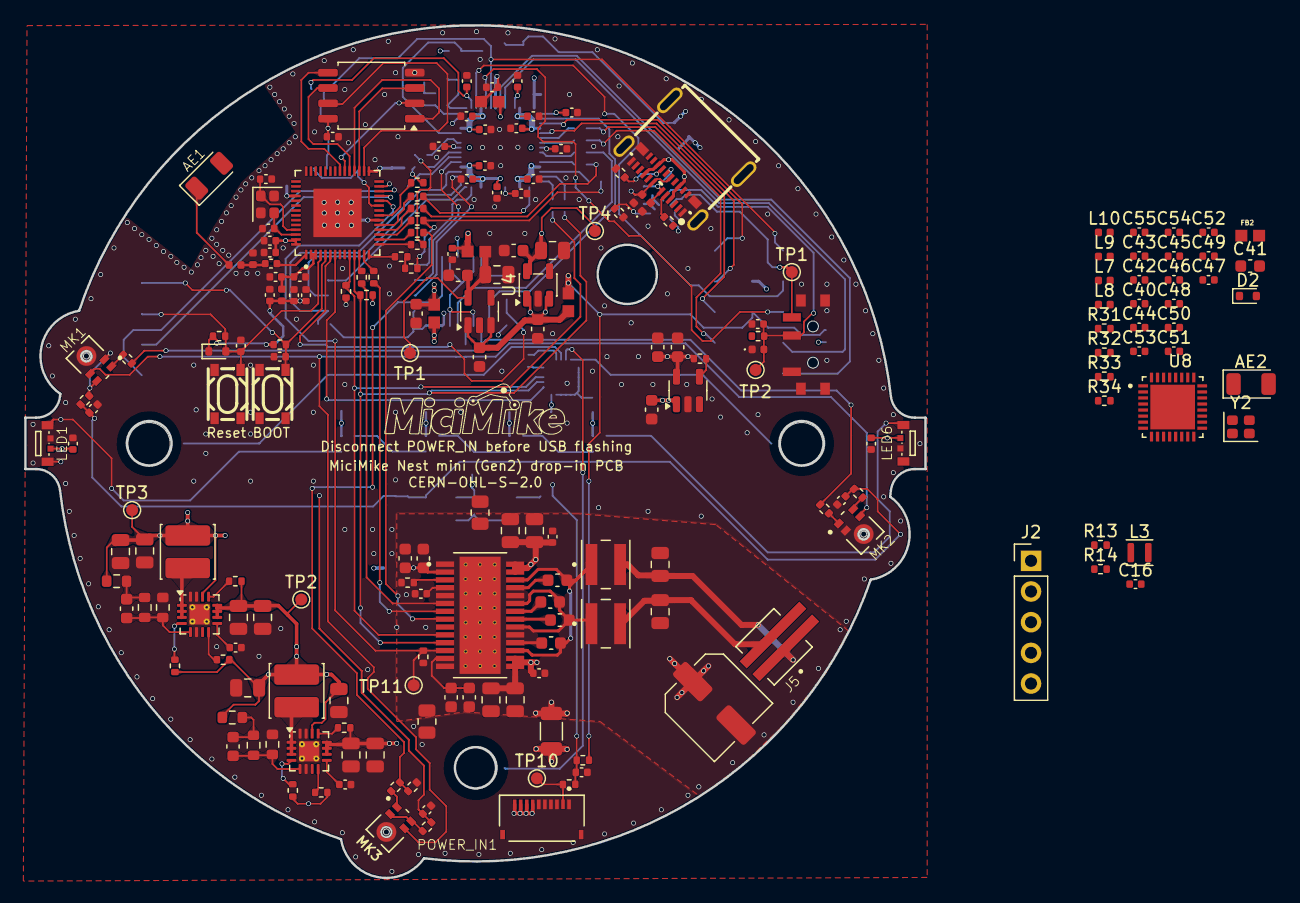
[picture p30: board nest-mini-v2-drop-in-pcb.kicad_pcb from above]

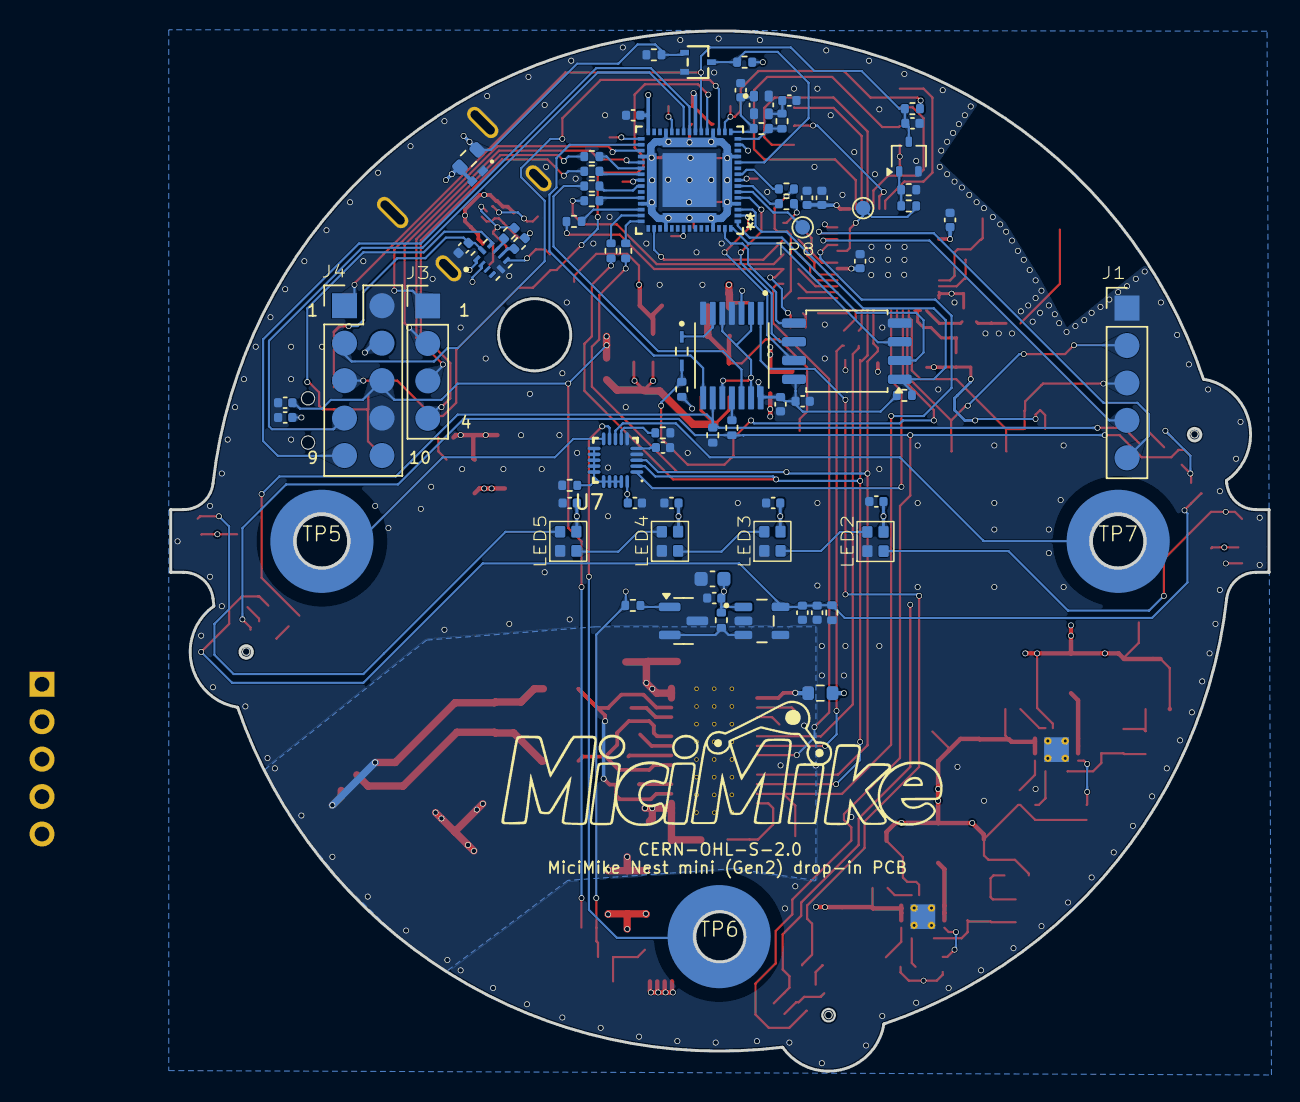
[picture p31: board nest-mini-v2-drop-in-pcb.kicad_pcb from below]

Board: 4 copper layers, 74.5 x 70.6 mm, 275 parts (76 on the bottom side), 164 nets.

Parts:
AE1, AE2: 2450AT18A100E; Johanson_2450AT18x100
C1, C8, C8#2: 10uF; C_0603_1608Metric
C1#2, C2#2, C26, C27, C29, C30, C31, C34, C36, C37, C47, C48, C49, C50, C54, C56, C57, C59, C60, C61, C63, C64, C65, C66, C69, C70, C71, C72, C73, C74, C75, C76, C77, C79, C80, C81, C83, C84, C85, C86, C87, C92, C97, C102, C106, C107, C108, C109, C110, C111: 100nF; C_0402_1005Metric
C2, C3, C12, C13, C93, C95, C98, C99: 22uF; C_0805_2012Metric
C4, C5, C9: 10uF; C_0805_2012Metric
C6, C7#2: 10nF; C_0402_1005Metric
C6#2, C18, C94, C104: 4.7uF; C_0603_1608Metric
C7, C21, C41, C96, C105: 100nF; C_0603_1608Metric
C10, C11: 220pF; C_0603_1608Metric
C14, C15, C19: 100nF; C_0805_2012Metric
C16: 22pF; C_0402_1005Metric
C17, C78: 2.2uF; C_0603_1608Metric
C20, C28, C32, C35, C38, C40, C51, C53, C58, C67, C82: 1uF; C_0402_1005Metric
C22, C23, C25, C42, C43, C44, C45: 12pF; C_0402_1005Metric
C24, C55: 1.2pF; C_0402_1005Metric
C33, C46: 2.4pF; C_0402_1005Metric
C39, C52: 10uF; C_0402_1005Metric
C62, C68: 20pF; C_0402_1005Metric
C88, C89, C90, C91: 0.22uF; C_0603_1608Metric
C100, C101: 0.68uF; C_0805_2012Metric
C103: 220uF; C_Elec_6.3x7.7
D1, D2: LRB520S-30T1G; D_SOD-523
D1#2: TPD1E10B06DPYR; TPD1E05U06DPYR
D2#2, D3, D4: PESD0402V05; D_0402_1005Metric
D3#2: RB521S30T1G; DIOM168X70N
FB1, FB2, FB4: 120R; BLM18PG121SN1D
FB1#2: 30R; R_0603_1608Metric
FB3, FB5: 600R; BLM18PG121SN1D
J1: usb_c; USB-C-SMD_TYPE-C-USB-18
J1#2: Conn_01x05; PinHeader_1x05_P2.54mm_Vertical
J2: C6 PROGRAM POGO; PinHeader_1x05_P2.54mm_Vertical
J3: XTAG DEV; PinHeader_1x04_P2.54mm_Vertical
J4: XMOS JTAG; PinHeader_2x05_P2.54mm_Vertical
J5: 1775443-2
L1, L2: 2.2uH; L_Cenker_CKCS4020
L3: DFE201610E1R0M; L_Murata_DFE201610P
L4, L10: 3.3nH; L_0402_1005Metric
L5, L9: 2.7nH; L_0402_1005Metric
L6, L8: 2.2nH; L_0402_1005Metric
L7: 24nH; L_0402_1005Metric
L11, L12: 10uH; XAL4040-103MEC
LED1, LED6: SK6812D-EC3210R; LED-SMD_4P_SK6812D-EC3210R
LED2, LED3, LED4, LED5: SK6805-EC20
MK1, MK2, MK3: MMICT390200012; MIC_T3902
POWER_IN1: FH34SRJ-10S-0.5SH_50_; HRS_FH34SRJ-10S-0.5SH_50_
Q1: LBSS138WT1G; SC-70-3_L2.1-W1.3-P0.65-LS2.1-BR
Q2: LBSS138WT1G; SOT-323_SC-70
Q3: BC847B; SOT-23
R1, R1#2, R2, R3, R4, R4#2, R5, R6, R9#2, R14, R42: 100k; R_0402_1005Metric
R2#2, R3#2, R38, R39: 22R; R_0402_1005Metric
R5#2: 5.1k; R_0402_1005Metric
R6#2, R17, R20, R21, R22, R23, R24, R25, R26, R27, R28, R41, R43, R44, R45, R46, R47, R71: 0R; R_0402_1005Metric
R7, R10: 49.9R; R_0603_1608Metric
R8: 210k; R_0603_1608Metric
R9: 40k; R_0603_1608Metric
R11: 68.1k; R_0603_1608Metric
R12: 22.1k; R_0603_1608Metric
R13: 51k; R_0402_1005Metric
R15, R16, R31, R32, R33, R34, R50, R59: 10k; R_0402_1005Metric
R18, R19, R51: 4.7k; R_0402_1005Metric
R29: 200k; R_0402_1005Metric
R30, R35: 1M; R_0402_1005Metric
R36: 680R; R_0402_1005Metric
R37, R52, R53, R66, R72: 47k; R_0402_1005Metric
R40, R48, R56, R57, R60, R61, R62, R63, R64, R65: 100R; R_0402_1005Metric
R49, R55: 470k; R_0402_1005Metric
R54: 3.3k; R_0402_1005Metric
R58: 1k; R_0402_1005Metric
R67: 0R; R_1206_3216Metric
R68: 0R; R_0603_1608Metric
R69, R70: 0R; R_0805_2012Metric
SW1: Reset; SW-SMD_4P-L4.2-W3.2-P2.15-LS4.5
SW2: BOOT; SW-SMD_4P-L4.2-W3.2-P2.15-LS4.5
SW3: CUS-12TB; CUS-12B
TP1, TP1#2, TP2, TP2#2, TP3, TP4, TP11: TestPoint; TestPoint_Pad_D1.0mm
TP5: TOUCH_R; Touchpad
TP6: TOUCH_C; Touchpad
TP7: TOUCH_L; Touchpad
TP8: TEST-POINT; TestPoint_Pad_D1.0mm
TP9: XU316_RST; TestPoint_Pad_D1.0mm
TP10: MUTE; TestPoint_Pad_D1.0mm
U1: TPS62065DSGR; SOT-23-5
U2, U3: TPS62130; VQFN-16-1EP_3x3mm_P0.5mm_EP1.68x1.68mm_ThermalVias
U2#2: TS3USB221ERSER
U4: TLV75518PDBVR; SOT-23-5
U4#2: AP22802AW5-7; SOT-23-5
U5: ESP32-S3R8; QFN40P700X700X90-57N
U6: W25Q128JVSIQ; SOIC-8_5.3x5.3mm_P1.27mm
U7: MPR121QR2
U8: ESP32-C6FH8; ESP32-C6FH4
U9: XU316-1024-QF60B-C24 ; XU316-1024-QF60B-C24
U10: W25Q32JVSSIQ; SOIC-8_5.3x5.3mm_P1.27mm
U11: SN74LVC125APWR; SOP65P640X120-14N
U12: TLV73333PDBVR
U13: TAS5805MPWPR
X1: 24MHz 12pF; X4-SMD-2.0X1.6MM
Y1, Y2: 40MHz; Crystal_SMD_2016-4Pin_2.0x1.6mm

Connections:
+0V9: C8.1, C8#2.1, C9.1, C16.1, FB3.1, L3.2, R13.1, TP1.1 (1_1), TP1#2.1 (1_1)
+1V8: C18.1, C19.1, C56.1, C57.1, C59.1, R50.2, TP4.1 (1_1), U4.5 (VOUT), U9.17 (VDDIOB18), U9.26 (VDDIOB18), U9.31 (USB_VDD18)
+3V3: C2#2.1, C13.1, C15.1, C17.1, C36.1, C72.1, FB1.1, FB2.1, FB4.1, L2.2, R10.1, R42.1, R68.1, SW3.P$3 (3), TP3.1 (1_1), U2#2.10 (VCC), U3.14 (VOS), U4.1 (VIN), U4.3 (EN), U7.20 (VDD), U9.30 (USB_VDD33)
+5V: C1.1, C3.1, C5.1, C12.1, C14.1, C76.1, C78.1, C79.1, C106.1, C107.1, C108.1, C109.1, C110.1, C111.1, J4.4, L1.2, LED1.4 (VDD), LED2.1 (VDD), LED3.1 (VDD), LED4.1 (VDD), LED5.1 (VDD), LED6.4 (VDD), R2.1, R4.1, R4#2.1, R6.1, R7.1, R55.2, TP2.1 (1_1), TP2#2.1 (1_1), U1.5 (EN), U2.14 (VOS), U3.10 (VIN), U3.11 (VIN), U3.12 (VIN), U4#2.1 (OUT), U12.1 (IN)
+14V: C2.1, C4.1, POWER_IN1.7, POWER_IN1.8, POWER_IN1.9, POWER_IN1.10, R1.1, R1#2.1, R3.1, R5.1, R67.1, U2.10 (VIN), U2.11 (VIN), U2.12 (VIN)
/ESP32-S3R8/SPI_CLK: U5.33 (SPICLK), U6.6 (CLK)
/ESP32-S3R8/SPI_CS0: U5.32 (SPICS0), U6.1 (~CS)
/ESP32-S3R8/SPI_D: U5.35 (SPID), U6.5 (DI/IO_{0})
/ESP32-S3R8/SPI_HD: U5.30 (SPIHD), U6.7 (~HOLD/~RESET/IO_{3})
/ESP32-S3R8/SPI_Q: U5.34 (SPIQ), U6.2 (DO/IO_{1})
/ESP32-S3R8/SPI_WP: U5.31 (SPIWP), U6.3 (~WP/IO_{2})
/ESP32-S3R8/TOUCH_IRQ: U5.7 (GPIO2), U7.1 (~IRQ)
/Power/0V9_FB: C16.2, R13.2, R14.1, U1.4 (FB)
/Power/USB_D_N: D4.2 (A2), J1.A7 (DN1), J1.B7 (DN2), R3#2.1
/Power/USB_D_P: D3.2 (A2), J1.A6 (DP1), J1.B6 (DP2), R2#2.1
/Power/USB_IN_D_N: R3#2.2, U2#2.7 (D-)
/Power/USB_IN_D_P: R2#2.2, U2#2.8 (D+)
/Power/USB_SEL: C1#2.1, D2#2.2 (A2), SW3.P$2 (2), U2#2.9 (S)
/XMOS/MIC_CLK: R40.2, U11.12 (4A)
/XMOS/MIC_CLK_M: MK1.4 (CLK), MK2.4 (CLK), MK3.4 (CLK), R57.1
/XMOS/MIC_DATA_1: U9.32 (X1D13), U11.8 (3Y)
/XMOS/MIC_DATA_2: U9.14 (X1D11), U11.3 (1Y)
/XMOS/MIC_DATA_M_1: R53.2, R60.1, R61.1, U11.9 (3A)
/XMOS/MIC_DATA_M_2: R52.2, R62.1, U11.2 (1A)
/XMOS/QSPI_CLK: U9.5 (X0D10), U10.6 (CLK)
/XMOS/QSPI_CS_N: R51.1, U9.3 (X0D01), U10.1 (~CS)
/XMOS/QSPI_D0: U9.59 (X0D04), U10.5 (DI/IO_{0})
/XMOS/QSPI_D1: U9.1 (X0D05), U10.2 (DO/IO_{1})
/XMOS/QSPI_D2: U9.60 (X0D06), U10.3 (~WP/IO_{2})
/XMOS/QSPI_D3: U9.2 (X0D07), U10.7 (~HOLD/~RESET/IO_{3})
/XMOS/RST_N: C77.1, J4.1, Q2.3 (D), R50.1, U9.21 (RST_N)
/XMOS/SPI_CS_N: TP8.1 (T_1), U9.6 (X0D00)
/XMOS/TCK: J4.7, U9.24 (TCK)
/XMOS/TDI: J4.3, U9.18 (TDI)
/XMOS/TDO: J4.5, U9.20 (TDO)
/XMOS/TMS: J4.9, U9.23 (TMS)
/XMOS/VBUS_DETEC: Q1.3 (D), R42.2, U9.11 (X1D09)
/XMOS/XL_DN0: J3.2, U9.35 (X1D17)
/XMOS/XL_DN1: J3.1, U9.33 (X1D16)
/XMOS/XL_UP0: J3.3, R38.2
/XMOS/XL_UP1: J3.4, R39.2
AUDIO_PA_EN: R72.2, TP11.1 (1_1), U5.24 (GPIO18), U13.12 (~PDN)
C6_3V3: C41.1, C47.2, C49.2, C50.1, C51.1, C52.1, C53.2, C54.2, D2.1 (K), FB2.2, L8.2, R31.1, R32.1, R33.1, R34.1, U8.5 (VDDPST1), U8.20 (VDDPST2), U8.29 (VDDA1), U8.32 (VDDA2)
C6_UA0RXD: U5.37 (SPICLK_P), U8.22 (U0RXD/GPIO17)
C6_UA0TXD: U5.36 (SPICLK_N), U8.21 (U0TXD/GPIO16)
C6_USB_N: J2.4, U2#2.4 (D2-), U8.16 (USB_D-/GPIO12)
C6_USB_P: J2.5, U2#2.3 (D2+), U8.17 (USB_D+/GPIO13)
DVDD: C104.1, C105.1, R68.2, U13.2 (DVDD)
ESP_3V3: C21.1, C26.1, C27.1, C28.2, C29.2, C30.1, C31.1, C32.1, C37.1, C38.1, C39.1, D1.1 (K), FB1.2, L6.2, R15.1, R16.1, R18.1, R19.1, R59.2, U5.20 (VDD3P3_RTC), U5.29 (VDD_SPI), U5.46 (VDD3P3_CPU), U5.55 (VDDA1), U5.56 (VDDA2), U6.8 (VCC)
ESP_BOOT: C25.1, J1#2.2, R16.2, SW2.1, U5.5 (GPIO0)
ESP_C6_GPIO9: C45.1, J2.2, R34.2, U5.44 (MTCK), U8.15 (GPIO9)
ESP_C6_RST: C40.1, D2.2 (A), J2.3, R31.2, U5.43 (GPIO38), U8.4 (CHIP_PU)
ESP_MUTE_DET: D3#2.2, R59.1, U5.6 (GPIO1)
ESP_RST: C20.1, D1.2 (A), J1#2.3, R15.2, SW1.1, U5.4 (CHIP_PU)
ESP_WS2812: LED1.3 (DIN), U5.27 (GPIO21)
GND: C1.2, C1#2.2, C2.2, C2#2.2, C3.2, C4.2, C5.2, C6.1, C6#2.2, C7.2, C7#2.1, C8.2, C8#2.2, C9.2, C12.2, C13.2, C14.2, C15.2, C17.2, C18.2, C19.2, C20.2, C21.2, C22.1, C23.1, C25.2, C26.2, C27.2, C28.1, C29.1, C30.2, C31.2, C32.2, C33.2, C34.2, C35.1, C36.2, C37.2, C38.2, C39.2, C40.2, C41.2, C42.1, C43.1, C44.2, C45.2, C46.2, C47.1, C48.2, C49.1, C50.2, C51.2, C52.2, C53.1, C54.1, C56.2, C57.2, C58.2, C59.2, C60.2, C61.2, C62.2, C63.2, C64.2, C65.2, C66.2, C67.2, C68.2, C69.2, C70.2, C71.2, C72.2, C73.2, C74.2, C75.2, C76.2, C77.2, C78.2, C79.2, C80.2, C81.2, C82.2, C83.2, C84.2, C85.2, C86.2, C87.2, C106.2, C107.2, C108.2, C109.2, C110.2, C111.2, D1#2.1 (A1), D2#2.1 (A1), D3.1 (A1), D4.1 (A1), J1.0, J1.A1 (GND_A), J1.A12 (GND_A), J1.B1 (GND_B), J1.B12 (GND_B), J1#2.1, J2.1, J4.2, J4.8, L5.1, L9.1, LED1.1 (GND), LED2.3 (GND), LED3.3 (GND), LED4.3 (GND), LED5.3 (GND), LED6.1 (GND), MK1.3_1 (GND), MK1.3_2 (GND), MK2.2 (SELECT), MK2.3_1 (GND), MK2.3_2 (GND), MK3.3_1 (GND), MK3.3_2 (GND), POWER_IN1.1, POWER_IN1.3, POWER_IN1.4, POWER_IN1.5, POWER_IN1.6, Q1.2 (S), Q2.2 (S), Q3.3 (E), R5#2.2, R6#2.1, R9.2, R12.2, R14.2, R29.1, R30.2, R37.2, R49.1, R52.1, R53.1, R66.1, R69.1, R70.1, SW1.2, SW2.2, SW3.P$1 (1), SW3.P$4, SW3.P$5, SW3.P$6, SW3.P$7, U1.1 (PGND), U1.3 (AGND), U2.6 (GND), U2.15 (GND), U2.16 (GND), U2.17 (GND), U2#2.5 (GND), U3.6 (GND), U3.15 (GND), U3.16 (GND), U3.17 (GND), U4.2 (GND), U4#2.2 (GND), U5.57 (GND), U6.4 (GND), U7.4 (ADDR), U7.6 (VSS), U8.33 (GND), U9.65 (GND), U10.4 (GND), U11.4 (2~OE), U11.7 (GND), U12.2 (GND), X1.2, X1.4, Y1.2, Y1.4, Y2.2, Y2.4
GNDA: C92.2, C93.2, C94.2, C95.2, C96.2, C97.2, C98.2, C99.2, C100.2, C101.2, C102.2, C103.2, C104.2, C105.2, R69.2, R70.2, R71.1, R72.1, U13.1 (DGND), U13.5 (DGND), U13.14 (AGND), U13.19 (PGND), U13.24 (PGND), U13.29 (POWERPAD), U13.30 (POWERPAD), U13.31 (POWERPAD), U13.32 (POWERPAD), U13.33 (POWERPAD), U13.34 (POWERPAD), U13.35 (POWERPAD), U13.36 (POWERPAD), U13.37 (POWERPAD), U13.38 (POWERPAD), U13.39 (POWERPAD), U13.40 (POWERPAD), U13.41 (POWERPAD), U13.42 (POWERPAD), U13.43 (POWERPAD), U13.44 (POWERPAD), U13.45 (POWERPAD), U13.46 (POWERPAD), U13.47 (POWERPAD), U13.48 (POWERPAD), U13.49 (POWERPAD), U13.50 (POWERPAD), U13.51 (POWERPAD), U13.52 (POWERPAD), U13.53 (POWERPAD)
I2C_SCL: R19.2, R46.2, U5.11 (GPIO6), U7.2 (SCL), U13.11 (SCL)
I2C_SDA: R18.2, R47.2, U5.10 (GPIO5), U7.3 (SDA), U13.10 (SDA)
I2S2_BCLK: R24.2, R44.2
I2S2_DATA: R17.1, R43.2
I2S2_LRCLK: R25.2, U9.47 (X0D39)
I2S2_MCLK: R23.2, R28.1, R45.2
I2S_BCLK: R27.2, U13.7 (SCLK)
I2S_DIN_ESP: R22.2, U13.8 (SDIN)
I2S_DIN_SEC: R21.2, R41.2
I2S_LRCK: R26.2, U13.6 (LRCLK)
I2S_MCLK: R20.2, R28.2
MUTE: POWER_IN1.2, R56.2, TP10.1 (1_1)
MUTE_ON: C81.1, R54.2, R56.1, R58.1, U11.1 (1~OE), U11.5 (2A), U11.10 (3~OE), U11.13 (4~OE)
unnamed: AE1.1, L4.1
unnamed: AE2.1, L10.2
unnamed: C10.1, R7.2, R8.1
unnamed: C11.1, R10.2, R11.1
unnamed: C24.1, L4.2, L5.2
unnamed: C33.1, C34.1, L6.1, U5.2 (VDD3P3), U5.3 (VDD3P3)
unnamed: C43.2, L7.2, Y2.3
unnamed: C44.1, R32.2
unnamed: C55.1, L9.2, L10.1
unnamed: C68.1, R36.2, X1.3
unnamed: C100.1, J5.1, L11.2
unnamed: C101.1, J5.2, L12.2
unnamed: D1#2.2 (A2), FB1#2.2, J1.A4 (VBUS_A), J1.A9 (VBUS_A), J1.B4 (VBUS_B), J1.B9 (VBUS_B)
unnamed: J1.B5 (CC2), R5#2.1
unnamed: L1.1, U2.1 (SW), U2.2 (SW), U2.3 (SW)
unnamed: L2.1, U3.1 (SW), U3.2 (SW), U3.3 (SW)
unnamed: LED1.2 (DOUT), LED2.4 (DIN)
unnamed: LED2.2 (DOUT), LED3.4 (DIN)
unnamed: LED3.2 (DOUT), LED4.4 (DIN)
unnamed: LED4.2 (DOUT), LED5.4 (DIN)
unnamed: LED5.2 (DOUT), LED6.3 (DIN)
unnamed: MK1.1 (DATA), R60.2
unnamed: MK1.2 (SELECT), MK1.5 (VDD), R63.2
unnamed: MK2.1 (DATA), R61.2
unnamed: MK2.5 (VDD), R64.2
unnamed: MK3.1 (DATA), R62.2
unnamed: MK3.2 (SELECT), MK3.5 (VDD), R65.2
unnamed: Q2.1 (G), R48.1, R49.2
unnamed: Q3.1 (B), R54.1
unnamed: Q3.2 (C), R55.1, U12.3 (EN)
unnamed: L3.1, U1.2 (SW)
unnamed: R1.2, R1#2.2, U2.8 (DEF)
unnamed: R3.2, U2.13 (EN)
unnamed: C10.2, R8.2, R9.1, U2.5 (FB)
unnamed: R5.2, U2.4 (PG)
unnamed: C6.2, U2.9 (SS/TR)
unnamed: R6#2.2, U2#2.6 (~OE)
unnamed: R2.2, U3.8 (DEF)
unnamed: R4.2, R4#2.2, U3.13 (EN)
unnamed: C11.2, R11.2, R12.1, U3.5 (FB)
unnamed: R6.2, U3.4 (PG)
unnamed: C7#2.2, U3.9 (SS/TR)
unnamed: R9#2.1, U4#2.4 (EN)
unnamed: R26.1, U5.12 (GPIO7)
unnamed: R27.1, U5.13 (GPIO8)
unnamed: R20.1, U5.14 (GPIO9)
unnamed: R21.1, U5.15 (GPIO10)
unnamed: R22.1, U5.16 (GPIO11)
unnamed: R23.1, U5.17 (GPIO12)
unnamed: R24.1, U5.18 (GPIO13)
unnamed: R25.1, U5.19 (GPIO14)
unnamed: C24.2, U5.1 (LNA_IN)
unnamed: R17.2, U5.21 (XTAL_32K_P)
unnamed: C23.2, U5.53 (XTAL_N), Y1.1
unnamed: C22.2, U5.54 (XTAL_P), Y1.3
unnamed: R30.1, U7.11 (ELEC3), U7.12 (ELEC4), U7.13 (ELEC5), U7.14 (ELEC6), U7.15 (ELEC7), U7.16 (ELEC8), U7.17 (ELEC9), U7.18 (ELEC10), U7.19 (ELEC11)
unnamed: R29.2, U7.7 (REXT)
unnamed: C35.2, U7.5 (VREG)
unnamed: C55.2, U8.1 (ANT)
unnamed: R33.2, U8.14 (GPIO8)
unnamed: C42.2, U8.30 (XTAL_N), Y2.1
unnamed: L7.1, U8.31 (XTAL_P)
unnamed: C67.1, FB5.1, U9.22 (PLL_AVDD)
unnamed: R43.1, U9.7 (X0D11)
unnamed: R44.1, U9.41 (X0D35)
unnamed: R45.1, U9.43 (X0D36)
unnamed: R46.1, U9.44 (X0D37)
unnamed: R47.1, U9.45 (X0D38)
unnamed: R41.1, U9.9 (X1D00)
unnamed: R38.1, U9.36 (X1D18)
unnamed: R39.1, U9.37 (X1D19)
unnamed: R40.1, U9.39 (X1D22)
unnamed: C62.1, R35.2, U9.16 (XIN), X1.1
unnamed: R35.1, R36.1, U9.15 (XOUT)
unnamed: D3#2.1, U11.6 (2Y)
unnamed: R57.2, U11.11 (4Y)
unnamed: R71.2, U13.3 (ADR/~FAULT)
unnamed: C94.1, C96.1, U13.13 (AVDD)
unnamed: C88.2, U13.25 (BST_A+)
unnamed: C90.2, U13.22 (BST_A-)
unnamed: C89.2, U13.18 (BST_B+)
unnamed: C91.2, U13.21 (BST_B-)
unnamed: C88.1, C89.1, L11.1, U13.17 (OUT_B+), U13.26 (OUT_A+)
unnamed: C90.1, C91.1, L12.1, U13.20 (OUT_B-), U13.23 (OUT_A-)
unnamed: C92.1, U13.4 (VR_DIG)
PVDD: C93.1, C95.1, C97.1, C98.1, C99.1, C102.1, C103.1, R67.2, U13.15 (PVDD), U13.16 (PVDD), U13.27 (PVDD), U13.28 (PVDD)
S3_USB_N: J1#2.4, U2#2.2 (D1-), U5.25 (GPIO19)
S3_USB_P: J1#2.5, U2#2.1 (D1+), U5.26 (GPIO20)
VBUS: C6#2.1, C7.1, FB1#2.1, Q1.1 (G), R9#2.2, R37.1, U4#2.5 (IN)
VDD: C58.1, C60.1, C61.1, C63.1, C65.1, C69.1, C71.1, C73.1, C74.1, FB3.2, FB5.2, U9.4 (VDD), U9.12 (VDD), U9.19 (VDD), U9.27 (VDD), U9.34 (VDD), U9.42 (VDD), U9.49 (VDD), U9.57 (VDD), U9.61 (VDD), U9.62 (VDD), U9.63 (VDD), U9.64 (VDD)
VDDA3P3: C46.1, C48.1, L8.1, U8.2 (VDDA3P3), U8.3 (VDDA3P3)
VDDIO: C64.1, C66.1, C70.1, C75.1, C80.1, C84.1, FB4.2, J4.6, R51.2, R58.2, U9.8 (VDDIOL), U9.38 (VDDIOR), U9.52 (VDDIOT), U10.8 (VCC), U11.14 (VCC)
VDD_MIC: C82.1, C83.1, C85.1, C86.1, C87.1, R63.1, R64.1, R65.1, R66.2, U12.5 (OUT)
XU316_RST: R48.2, TP9.1 (1_1), U5.23 (GPIO17)

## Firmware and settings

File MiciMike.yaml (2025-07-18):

substitutions:
  # Phases of the Voice Assistant
  # The voice assistant is ready to be triggered by a wake word
  voice_assist_idle_phase_id: '1'
  # The voice assistant is waiting for a voice command (after being triggered by the wake word)
  voice_assist_waiting_for_command_phase_id: '2'
  # The voice assistant is listening for a voice command
  voice_assist_listening_for_command_phase_id: '3'
  # The voice assistant is currently processing the command
  voice_assist_thinking_phase_id: '4'
  # The voice assistant is replying to the command
  voice_assist_replying_phase_id: '5'
  # The voice assistant is not ready
  voice_assist_not_ready_phase_id: '10'
  # The voice assistant encountered an error
  voice_assist_error_phase_id: '11'
  # Change this to true in case you ahve a hidden SSID at home.
  hidden_ssid: "false"

esphome:
  name: micimike-nappali
  friendly_name: MiciMike nappali
  on_boot:
    then:
      - light.turn_on:
          id: led_ring
          effect: slow_pulse
          red: 100%
          green: 60%
          blue: 0%
      - wait_until:
          condition:
            wifi.connected:
      - light.turn_on:
          id: led_ring
          effect: pulse
          red: 0%
          green: 100%
          blue: 0%
      - wait_until:
          condition:
            api.connected:
      - light.turn_on:
          id: led_ring
          effect: none
          red: 0%
          green: 100%
          blue: 0%
      - delay: 1s
      - script.execute: reset_led


esp32:
  board: esp32-s3-devkitc-1
  cpu_frequency: 240MHz
  variant: esp32s3
  flash_size: 16MB
  framework:
    type: esp-idf
    version: recommended
    sdkconfig_options:
      CONFIG_ESP32S3_DATA_CACHE_64KB: "y"
      CONFIG_ESP32S3_DATA_CACHE_LINE_64B: "y"
      CONFIG_ESP32S3_INSTRUCTION_CACHE_32KB: "y"

      # Moves instructions and read only data from flash into PSRAM on boot.
      # Both enabled allows instructions to execute while a flash operation is in progress without needing to be placed in IRAM.
      # Considerably speeds up mWW at the cost of using more PSRAM.
      CONFIG_SPIRAM_RODATA: "y"
      CONFIG_SPIRAM_FETCH_INSTRUCTIONS: "y"

      CONFIG_BT_ALLOCATION_FROM_SPIRAM_FIRST: "y"
      CONFIG_BT_BLE_DYNAMIC_ENV_MEMORY: "y"

      CONFIG_MBEDTLS_EXTERNAL_MEM_ALLOC: "y"
      CONFIG_MBEDTLS_SSL_PROTO_TLS1_3: "y"  # TLS1.3 support isn't enabled by default in IDF 5.1.5

wifi:
  id: wifi_id
  ssid: !secret ssid
  password: !secret wifi_pass
  output_power: 8.5dB
  power_save_mode: none
  reboot_timeout: 10min
  manual_ip:
    static_ip: 192.168.1.81
    gateway: 192.168.1.1
    subnet: 255.255.255.0
    dns1: !secret dns1
    dns2: !secret dns2
  ap:
    ssid: "${device_name}"
    password: !secret wifi_pass

captive_portal:

web_server:
  port: 80

logger:

ota:
  platform: esphome

api:
  id: api_id
  encryption:
    key: !secret api_key
  reboot_timeout: 10min
  services:
    - service: start_va
      then:
        - voice_assistant.start
    - service: stop_va
      then:
        - voice_assistant.stop
    - service: notification_on
      then:
        - script.execute: turn_on_notification
    - service: notification_clear
      then:
        - script.execute: clear_notification

button:
  - platform: restart
    name: "${friendly_name} újraindítás"
  - platform: safe_mode
    name: "${friendly_name} újraindítás (Safe Mode)"

i2c:
  - id: internal_i2c
    sda: GPIO5
    scl: GPIO6
    frequency: 400kHz

psram:
  mode: octal
  speed: 80MHz
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

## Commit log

2025-06-02 Add files via upload
    1st upload of the project files
    [OBJ_PCB_onju_by_imike78_2025-05-11.kicad_pcb, OBJ_PCB_onju_by_imike78_2025-05-11.kicad_sch, audio.kicad_sch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]
2025-06-02 Update and rename audio.kicad_sch to schematics/audio.kicad_sch
    [audio.kicad_sch]
2025-06-02 Update and rename esp32.kicad_sch to schematics/esp32.kicad_sch
    [esp32.kicad_sch]
2025-06-02 Update and rename leds.kicad_sch to schematics/leds.kicad_sch
    [leds.kicad_sch]
2025-06-02 Update and rename power_handling.kicad_sch to schematics/power_handling.kicad_sch
    [power_handling.kicad_sch]
2025-06-02 Update and rename xmos.kicad_sch to schematics/xmos.kicad_sch
    [xmos.kicad_sch]
2025-06-02 Update and rename OBJ_PCB_onju_by_imike78_2025-05-11.kicad_sch to schematics/OBJ_PCB_onju_by_imike78_2025-05-11.kicad_sch
    [OBJ_PCB_onju_by_imike78_2025-05-11.kicad_sch]
2025-06-15 Github desktop implemented
    [OBJ_PCB_onju_by_imike78_2025-05-11.kicad_pcb, OBJ_PCB_onju_by_imike78_2025-05-11.kicad_sch, audio.kicad_sch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]
2025-06-15 routing ongoing
    [OBJ_PCB_onju_by_imike78_2025-05-11.kicad_pcb]
2025-06-15 routing update
    [OBJ_PCB_onju_by_imike78_2025-05-11.dsn, esp32.kicad_sch, xmos.kicad_sch]
2025-06-18 routing finished
    [OBJ_PCB_onju_by_imike78_2025-05-11.kicad_pcb]
2025-06-18 DRC done
    [OBJ_PCB_onju_by_imike78_2025-05-11.kicad_pcb]
2025-06-19 production preparation
    [BOM_onju_by_imike78_2025-05-11.csv, OBJ_PCB_onju_by_imike78_2025-05-11.kicad_pcb, power_handling.kicad_sch]
2025-06-20 final touches
    [BOM_onju_by_imike78_2025-05-11.csv, OBJ_PCB_onju_by_imike78_2025-05-11.csv, OBJ_PCB_onju_by_imike78_2025-05-11.kicad_pcb]
2025-06-23 project name change
    Just removed the "onju" part from the name to avoid any issue with Justin, and state that thist is the V2 replacement board
    [OBJ_PCB_onju_by_imike78_2025-05-11.kicad_pcb, bom-JLCPCB Assembly Order.xls, nest-mini-v2-drop-in-pcb.csv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]
2025-06-24 modifications for manufacturing
    [1054500101.obj, 1054500101.step, 1054500101_3D.dxf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]
2025-06-24 removed unneccesary files
    [BOM.csv, BOM.xlsx, Question T-1M6W659778A-5sets-BOM_OBJ_PCB_onju_by_imike78_2025-05-11.kicad_pcb(2025-06-23).xlsx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]
2025-07-05 Remove ignored files
    [nest-mini-v2-drop-in-pcb.csv]
2025-07-18 rev2 update
    [DMM-3526-B-R.step, ESP32-S3R8.step, QFN_F60B-C24_XMO.step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]
2025-08-10 update for production
    [esp32.kicad_sch, leds.kicad_sch, nest-mini-v2-drop-in-pcb.kicad_pcb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]
2025-08-18 Add prototype image to README.md
    Add prototype image to README.md
2025-08-18 Adding two prototype images from iMike78
    Adding two prototype images from iMike78
2025-08-18 Second prototype picture showing it mounted
    Second prototype picture showing it mounted
2025-08-18 Add prototype 3D CAD image to readme as well
    Add prototype 3D CAD image to readme as well
2025-08-28 fixing errors
    [nest-mini-v2-drop-in-pcb.kicad_pcb, power_handling.kicad_sch]
2025-09-01 Update README.md with specs for MEMS microphones and RGB LED components
    Add specs for both MEMS microphones and RGB LED components to the list of known hardware specifications in readme file.
    Replaces old PR https://github.com/iMike78/nest-mini-drop-in-pcb/pull/29
2025-10-11 ESP32 and XMOS have own SPI flash
    Clearify that ESP32 and XMOS each have their own SPI flash
2026-02-12 complete redesign
    [audio.kicad_sch, leds.kicad_sch, nest-mini-v2-drop-in-pcb.kicad_pcb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]
2026-02-28 work in progress
    [audio.kicad_sch, esp32.kicad_sch, power_handling.kicad_sch]
2026-03-17 Update README mention Home Mini campaign
    Updated README to mention crowdfunding campaign for Google Home Mini PCB
2026-03-19 Revise README hardware spec replacing MAX98357A with TAS5805M
    Revise README hardware spec replacing MAX98357A with TAS5805M based on discussions:
    * https://github.com/iMike78/nest-mini-drop-in-pcb/discussions/16
    and
    https://github.com/rauli2780/nest-audio-pcb/discussions/7
    @iMike78 Note! Be aware that TAS5805M is more compex and also require a I2C connection to configure the DSP, so it not enough to just use I2S. For reference see Esparagus Audio Brick:
    * https://github.com/sonocotta/esparagus-media-center/
    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
2026-05-02 preparing for the test batch
    [xmos.kicad_sch]
2026-05-10 v2 hardware revision
    MPR121 touch controller added to replace the esp32-s3 internal touch interface
    [PCB_connections.xlsx, audio.kicad_sch, esp32.kicad_sch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]
2026-05-16 v2 hardware
    [esp32.kicad_sch]
2026-07-30 adding esp32c6 for OTBR
    [esp32.kicad_sch, esp32c6fh8_sch.kicad_sch, nest-mini-v2-drop-in-pcb.kicad_pcb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]
2026-09-24 WiP update
    [esp32.kicad_sch, nest-mini-v2-drop-in-pcb.kicad_pcb]
2026-09-28 Publish KiCad 10 hardware updates
    Refresh the Nest Mini v2 drop-in PCB project in KiCad 10 and publish the accumulated schematic and board updates as a single clean mainline change.
    Remove the unused USB-C power/input branch from the power sheet, including the USB connector path, data switching, VBUS switching, and associated support parts, while preserving the pogo-accessible USB signals where needed. Add the ESP32-C6 1x05 pogo connector with the J2-style pin order for GND, boot, reset, USB D-, and USB D+ without a 3.3 V pin.
    Add a 5 V SN74AHCT1G125 buffer for the LED data input, with local decoupling and a 47 ohm series output resistor, so the LED chain receives a buffered LED_WS2812_5V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
    [audio.kicad_sch, esp32.kicad_sch, esp32c6fh8_sch.kicad_sch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]
2026-09-28 Add LED data level buffer
    Add a 5 V SN74AHCT1G125 buffer on the LEDs sheet so the ESP_WS2812 control signal is translated to the LED_WS2812_5V data net before entering the LED chain.
    Place the buffer with its local support parts: a 100 nF VCC decoupling capacitor, fixed output enable wiring, and a 47 ohm series resistor at the buffered data output. Refresh the LEDs sheet symbol cache so the added buffer and resistor symbols are self-contained in the schematic.
    [leds.kicad_sch]
2026-10-05 Update README for current KiCad 10 hardware
2026-10-12 Publish ESP32-P4 multi-sheet hardware redesign
2026-10-20 Update KiCad schematics and PCB layout
2026-10-20 Rename ESP32 schematic sheets
2026-10-30 v3 hardware changes
    Full redesing, ready for prototype order
2026-10-30 Remove stale DRC report, old schematic PDF and schematic backup
    Claude-Session: https://claude.ai/code/session_01GX3ubaUMTpTY4jBpivFxad

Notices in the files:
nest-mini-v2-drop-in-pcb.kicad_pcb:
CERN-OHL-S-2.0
